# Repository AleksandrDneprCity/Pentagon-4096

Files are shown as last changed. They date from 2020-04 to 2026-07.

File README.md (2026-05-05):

# Pentagon-4096
This is new ZX-Spectrum clone
Версия 10.7.

Актуальные ревизии плат: Материнская плата (MainBoard) - 10.7.1. Верхняя плата (TopBoard) - 5.3.1.

Новый "Pentagon-4096", это новый клон ZX-Spectrum, собранный на классической мелкой логике, но с применением ARV микроконтроллеров.
Новый ZX-Spectrum совместимый компьютер вобрал в себя всё лучшее, что было в оригинальном Pentagon-128, но в него добавлены 
ряд исправлений и дополнений, реализованы ряд функциональных возможностей:

1) Полная совместимость, в том числе и по положению сигнала прерывания INT, с оригинальным "Pentagon-128". Но с возможностью переключения 
положения сигнала INT в положение "Фирменный ZX-Spectrum" (на 16 телевизионных строк вниз + на 13.71 мкс вправо), с целью исключения 
мерцания спрайтов в ряде фирменных играх.

2) Формирование видеосигнала с полностью стандартными синхро-импульсами и импульсами гашения, которые гарантируют нормальную работу с любым 
телевизором, а так же корректную работу PAL/NTSC и при необходимости, SECAM кодера.

3) Наличие PAL/NTSC кодера на микросхеме CXA1645 или CXA2075. Двумя перемычками можно выбирать стандарты: PAL 4.43 MHz, NSTC 3.58 MHz, NTSC 4.43 MHz.

4) Объём оперативной памяти 4 Мб с помощью 1 модуля SIMM 30 pin. Имеется возможность установки 1 модуля SIMM на 1 Мб, на плате имеется 
соответствующий джампер для переключения объёма установленного модуля памяти.

Вначале я хотел сделать ещё вариант установки двух модулей SIMM 30 pin по 1 Мб, но был вынужден отказаться от идеи, т.к. она не подружилась 
с турбированием ОЗУ на 7 МГц. Переключение модулей я делал стандартным способом - коммутацией сигнала CAS, но минимальной задержки 
этого сигнала оказалось достаточно, чтобы компьютер не заработал вообще. Хотя ещё оставалось конечно пару вариантов - коммутацию CAS 
я тогда сделал на К1531КП11, а нужно было попробовать на 1531ЛА3, но уже не буду возвращаться к этому варианту.

Расширении объёма памяти >128 КБ будет многостандартным, набор вариантов расширения памяти зависит от объёма установленного модуля SIMM 30 pin - 1МБ или 4МБ.

4.0: Доступные варианты расширения памяти для модуля SIMM 30 pin 1МБ:

4.0.0) Расширенную верхнюю память вообще можно отключить, оставив стандартные 128 КБ.

4.0.1) По стандарту "Пентагон-1024": За счёт дополнительных двух D6 и D7 битов порта 0x7FFD, а так же за счёт бита D5 (вместо блокировки),
получаем доступный объём ОЗУ 1024 КБ. Для совместимости с некоторыми программами, осбенно с фирменными, бит блокировки D5 этого порта
можно будет переназначать на своё первоначальное назначение - на блокировку всей верхней памяти (48 КБ). В этом случае доступный объём
ОЗУ будет составлять 512 КБ.

0x7FFD бит 7 - 256 КБ

0x7FFD бит 6 - 512 КБ

0x7FFD бит 5 - 1024 КБ (этот бит можно перенастроить на блокировку портов памяти, в этом случае доступный объём ОЗУ составит 512 КБ)

4.0.2) По стандарту "Профи-1024": За счёт порта 0xDFFD, битов D0, D1 и D2, ОЗУ будет доступно в объёме 1024 КБ:

0xDFFD бит 0 - 256 КБ

0xDFFD бит 1 - 512 КБ

0xDFFD бит 2 - 1024 КБ

4.0.3) За счёт чистого порта #1FFD, битов D4 и D7, ОЗУ будет доступно в объёме 512 КБ:

0x1FFD бит 4 - 256 КБ

0x1FFD бит 7 - 512 КБ

4.0.4) По стандарту "Kay-1024": За счёт порта 0x1FFD, битов D4 и D7, и порта #7FFD бита D7, ОЗУ будет доступно в объёме 1024 КБ:

0x1FFD бит 4 - 256 КБ

0x1FFD бит 7 - 512 КБ

0x7FFD бит 7 - 1024 КБ

4.1: Доступные варианты расширения памяти для модуля SIMM 30 pin 4МБ:

4.1.0) Расширенную верхнюю память вообще можно отключить, оставив стандартные 128 КБ.

4.1.1) По стандарту "Пентагон-1024": За счёт дополнительных двух D6 и D7 битов порта 0x7FFD, а так же за счёт бита D5 (вместо блокировки),
получаем доступный объём ОЗУ 1024 КБ. Для совместимости с некоторыми программами, осбенно с фирменными, бит блокировки D5 этого порта
можно будет переназначать на своё первоначальное назначение - на блокировку всей верхней памяти (48 КБ). В этом случае доступный объём
ОЗУ будет составлять 512 КБ.

0x7FFD бит 7 - 256 КБ

0x7FFD бит 6 - 512 КБ

0x7FFD бит 5 - 1024 КБ (этот бит можно перенастроить на блокировку портов памяти, в этом случае доступный объём ОЗУ составит 512 КБ)

4.1.2) По стандарту "Профи-1024": За счёт порта 0xDFFD, битов D0, D1 и D2, ОЗУ будет доступно в объёме 1024 КБ:

0xDFFD бит 0 - 256 КБ

0xDFFD бит 1 - 512 КБ

0xDFFD бит 2 - 1024 КБ

4.1.3) За счёт чистого порта #1FFD, битов D4 и D7, ОЗУ будет доступно в объёме 512 КБ:

0x1FFD бит 4 - 256 КБ

0x1FFD бит 7 - 512 КБ

4.1.4) По смешанному стандарту "Kay-1024" + "Pentagon-1024: За счёт порта 0x1FFD, битов D4 и D7, и порта #7FFD битов D6, D7 и D5, ОЗУ будет доступно в объёме 4096 КБ:

0x1FFD бит 4 - 256 КБ

0x1FFD бит 7 - 512 КБ

0x7FFD бит 6 - 1024 КБ

0x7FFD бит 7 - 2048 КБ

0x7FFD бит 5 - 4096 КБ (этот бит можно перенастроить на блокировку портов памяти, в этом случае доступный объём ОЗУ составит 2048 КБ)

4.1.5) По смешанному стандарту "Profi-1024" + "Pentagon-512: За счёт порта 0xDFFD, битов D0, D1 и D2, и порта #7FFD битов D6, D7, ОЗУ будет доступно в объёме 4096 КБ:

0xDFFD бит 0 - 256 КБ

0xDFFD бит 1 - 512 КБ

0xDFFD бит 2 - 1024 КБ

0x7FFD бит 6 - 2048 КБ

0x7FFD бит 7 - 4096 КБ

4.1.6) По смешанному стандарту "Profi-1024" + порт #1FFD: За счёт порта 0xDFFD, битов D0, D1 и D2, и порта #1FFD битов D4, D7, ОЗУ будет доступно в объёме 4096 КБ:

0xDFFD бит 0 - 256 КБ

0xDFFD бит 1 - 512 КБ

0xDFFD бит 2 - 1024 КБ

0x1FFD бит 4 - 2048 КБ

0x1FFD бит 7 - 4096 КБ

5) Наличие режима "Plus-3". Используются дополнительные 4 страницы ПЗУ, конфигурация ОЗУ становится такой же, как в фирменном 
"ZX-Spectrum+3" с поддержкой режимов "+3 SOS" и "+3 DOS" режимов.

6) В схеме имеется узел, который отлавливает команды короткой адресации к портам IN A,(xx), OUT (xx),A, благодаря которому, как только 
процессор попытается из ОЗУ извлечь код такой команды, моментально будет заблокирована вся верхняя память > 128 КБ, а порт 0x7FFD,
с помощью которого доступно ОЗУ объёмом 128 КБ, будет переведён на мягкую дешифрацию (с помощью битов A1 и A15). Как только процессор попытается из ОЗУ извлечь 
код любой другой команды, верхняя память разблокируется и порт #7FFD снова переводится на жёсткую дешифрацию.

7) Режим "Мультизадачность":
Мультизадачность можно будет включить через BIOS. В случае установленного модуля памяти SIMM 30 pin 4МБ, можно будет загружать в память до 31 задач одновременно.
Если будет установлен модуль памяти SIMM 30 pin 1МБ, то можно будет загружать в память до 7 задач одновременно.
Каждой задаче будет доступно 128 КБ памяти. Последний 32-й блок (или 8-й блок в случае установленного модуля SIMM 30 pin 1МБ) объёмом 128 КБ будет использоваться для хранения данных, необходимых для переключения на задачу.
Переключение между задачами планирую сделать по кнопке "Magic", где будет меню со списком загруженных задач.
 
8) Оперативная память турбирована на 7 МГц. Это позволило:
а) турбировать процессор Z80 на 7 МГц без WAIT-а, получив 200% производительности;
б) турбировать процессор Z80 на 14 МГц с WAIT-ом, получив 290% производительности;
в) реализовать дополнительные видеорежимы, требующие в 2 раза больше циклов доступа к ОЗУ видеоконтроллером, не останавливая процессор:
16 colors и 512х192 пикселей в цвете;

Из недостатков:

Компьютер будет работать не со всеми типами процессоров Z80. Отлично работает Z84C0020PEC, и их не сложно достать, поэтому в данном
проекте нужно использовать только этот процессор.

Возможно, придётся подбирать модули памяти SIMM. Обычно проблем не возникает с 3-чиповыми. В частности, отлично работают Motorolla, 
Samsung и др. Из всех не захотели работать только Panasonic. А вот 9-чиповые глючат, одни больше, другие меньше. из 7 или 8 разных 
модулей мне удалось подобрать только 2, которые более-менее нормально заработали, но всё равно хуже чем 3-чиповые.

Сложность в поиске быстрых микросхем логики серии КР1531. К счастью, не весь компьютер нужно собирать на этой серии, а только критичные 
к задержкам сигналов узлы. А то что достать не удалось, можно заменить на импортые аналоги серии 74Fxxx. 

Из дополнительных недостатков Турбо-14 МГц:

В этом режиме почему-то не хочет работать ОС iS-DOS, который зависает почти сразу после запуска, иногда портится при этом диск C: на HDD.
В то же время, все остальные проверенные мной программы, прекрасно раотают в режиме Турбо-14 МГц.

8) Шина Nemo-Bus v1.0 содержит 4 слота.

9) Возможность установки карт расширения "Plus-3". Для этого есть специальная плата-адаптер "NemobusToDivIDE", в которую можно будет устанавливать карты расширения 3+.
Эта плата устанавливается в слот NemoBus, а на неё саму устанавливается карта +3.

Дополнительная задача платы-адаптера является разрешение конфликтов устройства DivIDE с GeneralSound, у которых совпадают 2 порта 0xB3 и 0xBB.
Для разрешения конфликтов на плате реализован порт 0x33, который управляет блокировкой IORQ на карту +3 и генерацией IORQGE при обращении к портам 0xB3 и 0xBB.
Карта адаптера с установленным в неё DivIDE, должна быть установлена в слот NemoBus с большим приоритетом относительно General Sound. 
Перемычка на карте-адаптере должна быть снята.

В исходном состоянии IORQ на карту +3 не проходит, и IORQGE не генерируется, поэтому при обращении к портам 0xB3 и 0xBB отзываться будет General Sound.
Для того чтобы обратиться к DivIDE, необходимо в порт 0x33 выдать значение 0x10 (бит D4). IORQ для DivIDE разблокируется и при обращении к портам 0xB3 и 0xBB будет генерироваться IORQGE,
таким образом General Sound не будет мешать работе DivIDE.
Для того чтобы вернуть доступ к General Sound, достаточно в порт 0x33 записать значение 0.

Если в карту NemoBusToDivIDE будет установлена любая другая карта +3, которая не конфликтует с General Sound, то можно отключить блокировку IORQ, установив на карте-адаптера перемычку.
В этом случае управлять портом 0x33 не нужно.

11) Плюс 1 слот ISA специально для модема, включенного по схеме Кондратьева, полный вариант с прерыванием от модема IRQ4 по NMI. Использовать 
можно, к примеру, в iS-DOSе, можно будет с ПЦ и обратно перекачивать файлы размером больше дискеты, не придётся дёргать винчестер 
и подключать его к ПЦ. Испытал на себе, это удобно. Сигнал IORQG для модема будет последним в приоритете после 4-го слота ZX-Bus.

12) Наличие мышки PS/2, контроллер на Attiny2313, с буфером, без WAITа.

13) Возможность подключения как классической механической клавиатуры, так и PS/2 без WAIT, контроллер на ATMega48PA-PU.

14) Наличие порта RS-232 с использованием музыкального сопроцессора AY и микросхемы MAX3232.

15) Турбирование контроллера дисковода КР1818ВГ93 по правильной схеме, с учётом всех исправлений описанных журнале "Спектрофон" № 12 и 14.

16) NemoIDE контроллер.

17) Доступ к 0-й странице ПЗУ с прошивкой Gluk Reset Service.

18) Наличие порта атрибутов, с использованием полной дешифрации порта 0xFF.

19) Теневое ОЗУ ёмкостью 128 Кб. Будет выполнять 2 функции - в качестве стандартного теневого ОЗУ, включающееся и выключающееся через 
чтение из портов 0xFB, 0x7B, ёмкостью 16 или 32 Кб, и для подмены всех 8х страниц ПЗУ Spectrum:

Страница 0 - стандартное теневое ОЗУ через IN A,(#FB)/IN A,(#7B), либо эмуляция 0-й страницы ПЗУ Gluk Reset Service;

Страница 1 - только эмуляция 1-й страницы ПЗУ TR-DOS;

Страница 2 - расширение стандартного теневого ОЗУ до 32Кб, либо эмуляция 2-й страницы ПЗУ Menu-128;

Страница 3 - только эмуляция 3-й страницы ПЗУ Basic-48.

Страница 4 - эмуляция 0-й страницы ПЗУ Редакто Basic-128 +3

Страница 5 - эмуляция 1-й страницы ПЗУ Обработчик ошибок Basic-128 +3

Страница 6 - эмуляция 2-й страницы ПЗУ Basic-48 +3

Страница 7 - эмуляция 3-й страницы ПЗУ +3 DOS

19) Микросхема CMOS-часиков по схеме MrGluk. Можно устанавливать как Dallas, так и МС146818 или её аналог 512ВИ1. Тактирование последних 
двух происходит от экономичной микросхемы MC14069. Внешняя батарейка - CR2032, которая будет использоваться для любого варианта CMOS, 
в том числе и для Dallas (в случае, если используется старый чип Dallas с давно разряженной внутренней батарейкой).
Порты для управления CMOS - 0xBFF7, 0xDFF7 и 0xEFF7.

20) 9 расширенных видеорежимов (в скобках кол-во циклов доступа к ОЗУ видеоконтроллером за 1 адрес):

20.0) "Стандартный видеорежим". 256х192 pix, атрибут цвета на знакоместо 8х8, разрешение для атрибутов 32х24. Область пикселей - 0x4000 - 0x57FF, область атрибутов - 0x5800 - 0x5AFF 
(2 цикла чтения из ОЗУ);

20.1) "Аппаратный мультиколор". 256х192 pix, атрибут цвета на байт 8х1, разрешение для атрибутов 32х192. Область пикселей - 0x4000 - 0x57FF, область атрибутов - 0x6000 - 0x77FF 
(2 цикла чтения из ОЗУ);

20.2) "512х192 pix, монохромный". Через порт BIOS можно выбрать любой цвет текста. Область пикселей нечётного знакоместа - 0x4000 - 0x57FF, область 
пикселей чётного знакоместа - 0x6000 - 0x77FF (4 цикла чтения из ОЗУ, для совместимости с цветным вариантом);

20.3) "512х192 pix, цветной". Атрибут на знакоместо 8х8, разрешение для атрибутов 64х24. Область пикселей нечётного знакоместа - 0x4000 - 0x57FF, область 
атрибутов нечётного знакоместа - 0x5800 - 0x5AFF, область пикселей чётного знакоместа - 0x6000 - 0x77FF, область атрибутов чётного 
знакоместа - 0x7800 - 0x7AFF (4 цикла чтения из ОЗУ);

20.4) "512х192 pix, мультиколорный". Атрибут на байт 8х1, разрешение для атрибутов 64х192. Область пикселей нечётного знакоместа - 0x4000 - 0x57FF, область пикселей 
чётного знакоместа - 0x6000 - 0x77FF, область атрибутов нечётного знакоместа - 0xC000 - 0xD7FF 4-й страницы, область атрибутов чётного 
знакоместа - 0xE000 - 0xF7FF 4-й страницы (4 цикла чтения из ОЗУ);

20.5) "16 colors" - каждый пиксель своим цветом. Экран состоит из 4-х экранных областей: 0x4000 - 0x57FF, 0x6000 - 0x77FF, 0xC000 - 0xD7FF 
4-й страницы, 0xE000 - 0xF7FF 4-й страницы. Каждый байт данных отображает 2 пикселя, каждая экранная область отображает свои 2 пикселя из знакоместа, 4 области составляют целое знакоместо (4 цикла чтения из ОЗУ);

20.6) "384х288 pix, полноэкранный режим без бордюра". Разрешение для атрибутов 48х36 (2 цикла чтения из ОЗУ);

20.7) "FlashColor". Можно применять в комбинации с видеорежимами 20.0, 20.1, 20.3, 20.4 и 20.6. Внутри каждого цветного атрибута, в котором активирован 7-й бит "флеш", вместо стандартного мигания знакоместа, перемешиваются цвета пикселей и фона и выводятся результат для пикселей, цвет фона при этом чёрный.

20.8) "Аппаратный GigaScreen", автоматический. Можно применять в комбинации с любым видеорежимом. Выводит на экран основной и дополнительный экраны с черезстрочным чередованием, с инверсией переключения через кадр. Включается при условии, если программа просмотра гигаскрин-картинок начинает переключать по прерываниям основной / дополнительный экран. Когда переключение произошло, запускается переключение экранов через строку и продолжается до прихода кадрового импульса. Если программное переключение экранов прекратилось, аппаратный гигаскрин не включается. За счёт черезстрочного переключения экранов, мерцание на гигаскрин картинках становится значительно менее заметно.

Видеорежимы "Аппаратный мультиколор", "512х192", "16 colors" и "384х288" включаются стандартным портом 0xEFF7.
Видеорежим "512х192" из монохромного в цветной или обратно переключается дополнительным портом 0xFE37, управляемый из BIOS.
Видеорежим "512х192" мультиколорный включается, если через 0xEFF7 включить одновременно режимы "Мультиколор" и "512х192", а так же 
включить цвет портом 0xFE37.

20.9) Регистр палитры (совместим с АТМ Турбо 2+): Возможность переопределять стандартные 16 цветов на любые из палитры 4096 цветов. Палитра обеспечивает 12 битный цвет: для каждой компоненты R, G, B можно задавать любое 4-битное значение. Таким образом получается по 16 уровней для красного, зелёного и синего, что в совокупности даёт 4096 цветов и оттенков.

Программируется палитра в момент, пока на экране отображается бордюр. Для этого необходимо сначала задать номер исходного цвета из 16, который необходимо переназначить, включив соответствующий Border:

биты 0, 1 и 2 - записывая в порт #FE значения от 0 до 7, бит 3 - записывая в порт #F6 значение 8.

Затем задать нужный цвет из палитры путём записи в порт # xxFF значение цвета. При этом по шине данных задаются первые 6 бит цвета, а по шине адреса - вторые 6 бит.

Раскладка 12-битного цвета при записи в порт #xxFF:

||| Палитра: ||| R0... | R1... | R2... | R3... ||| G0... | G1... | G2... | G3... ||| B0... | B1... | B2... | B3... |||

||| Порт #FF ||| A14 | A9... | D6... | D1... ||| A15 | A12 | D7... | D4... ||| A13 | A8... | D5... | D0... |||

21) SoundDrive с поддержкой режима Covox. В качестве микросхем ЦАП использованы TLC7528, что значительно упростило принципиальную схему.

22) BIOS с тестированием ОЗУ и Setup-ом. Установлена дополнительная микросхема ПЗУ ёмкостью 64 Кбайта. 

22.1) В BIOS-Setup можно:

22.1.1. Выставлять текущую дату и время;

22.1.2. Настроить расширенные видеорежимы:

а) выбрать цвет текста для монохромного видеорежима 512х192;

б) включить или отключить цвет для видеорежима 512х192;

в) включить или отключить флешколор;

г) включить или отключить автоматический аппаратный гигаскрин.

3. Настроить теневое ОЗУ - включать и отключать эмуляцию ПЗУ для каждой из 4-х страниц;

4. Настроить поведение Спектрума при сбросе:

а) Выход в Gluk Reset Service;

б) Выход в Menu-128;

в) Выход в TR-DOS;

г) Выход в TR-DOS без очистки ОЗУ;

д) Выход в Basic-48;

е) Загрузка с HDD Master;

ж) Загрузка с HDD Slave;

з) При выборе варианта загрузки с HDD, можно выбирать варианты, что именно загружать:

DNA-OS;

iS-DOS;

пользовательский вариант номера блока LBA.

22.1.3. Выбрать порты расширения верхней памяти >128 КБ;

22.1.4. Включать и отключать режим Мультизадачности.

23) Конструктивно всё это собрано на двух платах: Материнская плата имеет размер стандартного ATX, что позволит её установить 
в стандартный корпус ATX, разводка 4-слойная. Вторая плата имеет размеры 170x170 мм и будет крепиться к материнской плате вверху 
и на ней будут располагаться 5 внешних коннекторов: Сдвоенный PS/2 - мышка + клавиатура, DB15 (female) - механическая клавиатура, 
DB9 (female) - кэмпстон джойстик, DA-15 (VGA), S-Video и RCA 3 шт - видео и аудио стерео. 
Остальные коннекторы - 3 шт. мини-джек (аудио-выход, магнитофонные вход и выход), DB9 (male - порт RS-232) и DB25 (принтер) придётся 
разместить на планках.

Описание портов BIOS:

#FC37 "Конфигурация памяти":

    bit 0, 1 - выбор 1-го порта расширения ОЗУ > 128 КБ (EM0):
    0 - выкл,
    1 - Пентагон-1024 (#7FFD)
    2 - Профи-1024 (#DFFD)
    3 - Scorpion/KAY (#1FFD)

    bit 2, 3 - выбор 2-го порта расширения ОЗУ > 128 КБ (EM1):
    0 - выкл,
    1 - Пентагон-1024 (#7FFD)
    2 - Профи-1024 (#DFFD)
    3 - Scorpion/KAY (#1FFD)

Совместное использование 1-го и 2-го портов расширения (EM0 и EM1) подчиняется следующей таблице:

        Биты порта #FC37:
        3  2     1  0
        EM1      EM0          SIMM 1M          SIMM 4M            Max Size                                      Size (без участия бита защёлки D5 7FFD)
    
    0)  0  0     0  0         128K             128K                128K                                          128K
    1)  0  0     0  1         Pent-1M          Pent-1M              1M (#7FFD биты 6, 7, 5)                      512K (#7FFD биты 6, 7)
    2)  0  0     1  0         Profi-1M         Profi-1M             1M (#DFFD биты 0, 1, 2)                       1M (#DFFD биты 0, 1, 2)
    3)  0  0     1  1         #1FFD            #1FFD               512K (#1FFD биты 4, 7)                        512K (#1FFD биты 4, 7)
    4)  0  1     1  1         KAY-1M           KAY-1M+Pent          4M (#1FFD биты 4, 7, #7FFD биты 6, 7, 5)      2M (#1FFD биты 4, 7, #7FFD биты 6, 7)
    5)  1  0     1  0         Profi-1M         Profi-1M+Pent        4M (#DFFD биты 0, 1, 2, #7FFD биты 6, 7)      4M (#DFFD биты 0, 1, 2, #7FFD биты 6, 7)
    6)  1  1     1  0         Profi-1M         Profi-1M+1FFD        4M (#DFFD биты 0, 1, 2, #1FFD биты 4, 7)      4M (#DFFD биты 0, 1, 2, #1FFD биты 4, 7)

Примечание-1: В любой из выбранной конфигурации ОЗУ, где задействуется бит 5 порта #7FFD для расширения ОЗУ, доступность такого расширения зависит от опции BIOS "Бит 5 #7FFD защёлка или расширение".

Примечание-2: Конфигурация № 5 является исключением из правил - для задействования двух портов #DFFD и #7FFD, EM0 и EM1 оба должны быть = 2.

    bit 4 - опция "Бит 5 #7FFD защёлка или расширение". Если этот бит = 0, тогда бит 5 порта #7FFD расширяет ОЗУ, в противном случае работает как обычная защёлка 48 КБ.
    bit 5 - включение режима загрузки данных в статическое ОЗУ. При активации этого бита, в адреса #C000 - #FFFF вместо основного ОЗУ подставляется статическое ОЗУ с полным доступом. 
Выбор страницы статического ОЗУ осуществляется через порт #7FFD битами 0 и 1, что даёт доступ в пределах 64 КБ, а так же включение или отключением режима "3+", что даёт выбор между первыми и вторыми 64 КБ статического ОЗУ. Если в порту #7FFD активировать бит 2, то вместо статического ОЗУ снова включается основное ОЗУ. Сделал это для возможности использовать отладчик STS 3.3, который висит в 7-й странице ОЗУ.
    bit 6 - включение режима "Мультизадачность".
    bit 7 - включение режима "3+".

#FD37: - выбор страниц эмуляции основного ПЗУ в статическом ОЗУ. При активации какого-либо бита этого порта, выбранная страница основного ПЗУ, которая соответствует биту порта BIOS, подменяется на соответствующую страницу из статического ОЗУ. В этом режиме выбранные страницы статического ОЗУ доступны в режим "только чтение".

#FE37: - дополнительные видеорежимы.

    bit 0, 1, 2 - цвет текста (B, R, G) в монохромном режиме 512x192.
    bit 3 - яркость текста в монохромном режиме 512x192.
    bit 4 - включение цвета в режиме 512x192.
    bit 5 - видеорежим "FlashColor".
    bit 6 - видеорежим "Аппаратный GigaScreen с автовключением".
    bit 7 - выбор положения INT: 0 = Пентагон, 1 = Фирменный.

#FF37: - управление ПЗУ и блокировками.

    bit 0 - отключает ПЗУ BIOS и включает основное ПЗУ "Spectrum".
    bit 1 - отключает блокировку защёлки сервисной страницы ПЗУ "Gluk Reset Service".
    bit 2, 3 - выбор страницы ПЗУ BIOS в пределах первых 3-х страниц. Последняя страница ПЗУ BIOS задействована в качестве ПЗУ Принтера, поэтому недоступна для режима BIOS.
    bit 4 - блокировка включения режима "кеш память".
    bit 5 - разрешает запись в регистры палитры.
    bit 6 - включение режима записи в основное ПЗУ "Spectrum".
    bit 7 - включение режима стирания основного ПЗУ "Spectrum".

Раскладка порта конфигурации #EFF7:

    bit 0 - видеорежим "16 Colors" - каждый пиксель своим цветом.
    bit 1 - видеорежим "512х192" - удвоенное разрешение по горизонтали.
    bit 2 - не используется.
    bit 3 - проецирование 0-й страницы ОЗУ в адресное пространство ПЗУ #0000 - #3FFF.
    bit 4 - не используется.
    bit 5 - видеорежим "Мультиколор" - атрибут цвета на байт.
    bit 6 - видеорежим "384x304" - экран без бордюра.
    bit 7 - открытие скрытых портов RTC и FDC.
    
Видеорежимами можно управлять двумя портами: 

#EFF7 - основной стандартный порт управления видеорежимами;

#FE37 - дополнительный порт BIOS управления видеорежимами.

        #EFF7:                  #FE37:
    0)  X 0 0 0 - X 0 0 0       X 0 0 X - X X X X        Стандартный видеорежим
    1)  X 0 1 0 - X 0 0 0       X X X X - X X X X        "Аппаратный мультиколор" (атрибут цвета на байт)
    2)  X 0 0 0 - X 0 0 1       X X 0 X - X X X X        "16 Colors" (каждый пиксель своим цветом)
    3)  X 0 0 0 - X 0 1 0       X X X 0 - I G R B        "512x192 монохромный", цвет текста задаётся битами I G R B порта #FE37
    4)  X 0 0 0 - X 0 1 0       X X X 1 - X X X X        "512x192 цветной", атрибут цвета на узкое знакоместо размером 8х8 пикселей
    5)  X 0 1 0 - X 0 1 0       X X X 1 - X X X X        "512x192 цветной мультиколорный" - атрибут цвета на узкий байт размером 8x1 пикселей
    6)  X 1 0 0 - X 0 0 0       X X X X - X X X X        "384x304" - экран без бордюра, количество пикселей без учёта строчных и кадровых гасящих импульсов
    7)  X X X 0 - X 0 X 0       X X 1 X - X X X X        "FlashColor" - бит 7 атрибута цвета вместо мигания активирует палитру INK (кроме монохромного режима 512х192 и 16 Colors)
    8)  X X X 0 - X 0 X X       X 1 X X - X X X X        "Аппаратный GigaScreen" - перекл. осн. и доп. экран каждую строку, вкл/выкл автоматически по факту программного переключения экранов

Примечание-1:
При включении через порт #FE37 режима "Аппаратный GigaScreen", фактически он включается с момента однократного программного переключения экранов, осуществляя их аппаратное переключение вначале каждой строки, и отключается в конце кадра.

Примечание-2:
Видеорежим "16 Colors" не совместим с видеорежимами "Мультиколор", "512x192" цветным и монохромным, "384x304" и "FlashColor".

Примечание-3:
Видеорежим "384x304" не совместим с видеорежимами "Мультиколор", "512x192" цветным и монохромным и "16 Colors".

Примечание-4:
Видеорежим "Аппаратный GigaScreen" совместим со всеми остальными видеорежимами, его можно комбинировать с любым другим видеорежимом.

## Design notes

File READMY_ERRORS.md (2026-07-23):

Обнаруженные ошибки в схеме:

Материнская плата, версия 10.7:

1) При открытии портов TR-DOS (при открытии доступа к чипу RTC - Real Time Clock) через порт #EFF7 бит 7, возникает конфликт портов TR-DOS с портами конфигурации #EFF7 и портом атрибутов #FF.
  Необходимо в дешифратор портов TR-DOS добавить проверку адреса A3 на 1.
  В более простом варианте решения, необходимо перекинуть местами 2 логических элемента: 4И (DD15.2 - 1533ЛИ6) и 2И (DD132.2 - 1533ЛИ1). На два свободных входа ЛИ6 подаём дополнительные адреса от процессора A2 и A3.
2) На адресный вход A1 микросхемы контроллера дисковода КР1818ВГ3 (DD135 выв.6) перепутал адрес от процессора - подал A1 вместо A6.
   Отрезаем A1 от выв.6 DD135 (1818ВГ93) и подаём туда A6.
3) Не соединил вместе выводы 28 (HLD) и 32 (RDY) микросхемы контроллера дисковода КР1818ВГ93.
   Соединяем между собой выводы 28 и 32 DD135 (1818ВГ93).
4) С учётом особенностей применения в качестве регистра пикселей, микросхемы КР1533ИР9 вместо двух привычных микросхем К555ИР16, требуется дополнительная небольшая задержка тактового сигнала,
   при чём для двух видеорежимов 256x192 и 512x192 пикселей задержка должна быть разной, для 256x192 больше, а для 512x192 меньше.
   а) ёмкость конденсатора C6 возле ИР9 уменьшаем со 100 до 47 пф (начинает работать видеорежим 512х192).
   б) отрезаем от входа микросхемы DD104 (1531КП11) выв.11 сигнал F7 и подаём его туда через резистор 680 Ом, вешаем конденсатор 47 пф между землёй и выв.11 этй же микросхемы.
5) Ошибка в ловушке команд OUT (xx),A и IN A,(xx), предназначенной для разрешения конфликтов портов расширения ОЗУ выше 128 КБ (1FFD, DFFD) при использовании команд короткой адресации порту FD.
   а) отрезаем сигнал ММ1 от выв.11 DD68.1 (1533ТМ2);
   б) подаём на выв.11 DD68.1 (1533ТМ2) инверсный сигнал M1 прямо с процессора с выв.27.
   в) желательно закоротить резистор R7 в цепи инверсного сигнала M1, в таком случае на микросхему DD68 его можно подать от соседней микросхемы на плате.
6) Порт #1FFD +3: При обращении к этому порту, ошибочно использовал сигнал WR, который подан на микросхему DD78.4 (1533ЛЕ1) выв.12. Вместо сигнала WR туда необходимо подать сигнал WRHR,
   в который заведены блокировки: при срабатывании ловушки команд OUT (xx),A и IN A,(xx), при блокировке памяти выше 48 КБ через порт #7FFD бит 5.
   а) отрезаем сигнал WR от выв.12 DD78;
   б) подаём сигнал WRHR, соединяя между собой выводы 3 и 12 DD78.   
7) С учётом применения буфера шины данных на 1531АП6, необходимо чуть-чуть притормозить тактовые сигналы портов #FE (бордюр, биппер) и #EFF7.
   Берём 2 конденсатора по 220 пф, припаиваем их: между выв.9 DD147 (ТМ9) и землёй, и между выв.9 DD93 (ТМ9) и землёй.
8) Ошибка в схеме многозадачности:
   При включении многозадачности сигналом BIOS "MTASK_ON", необходимо чтобы биты расширения ОЗУ выше 128 КБ, вместо привычного проецирования выбранной страницы 16 КБ в адресное окно #C000 - #FFFF,
   производили замену целого блока ОЗУ размером 128 КБ на выбранный. Так же необходимо на выбранный блок 128 КБ проецировать оба экрана.
   Для исправлении ошибки понадобятся дополнительный логический элемент И на 1531ЛИ1, и любой инвертирующий элемент.
   а) дополнительный элемент "И" можно взять DD54.3 или DD54.4, если вместо 1533ЛИ1 установлена 1531ЛИ1. Оба логических элемента в схеме по ошибке выполняют одну и ту же функцию с одними и теми же сигналами.
   Освобождаем один из них, переложив всё на другой элемент;
   б) в качестве инвертирующего элемента моожно использовать свободный элемент DD113.4 (ЛП5);
   в) формируем инверсный сигнал "MTASK_ON" с помощью элемента DD113.4 (ЛП5). На вход-1 подаём прямой сигнал "MTASK_ON", на вход-2 подаём +5 вольт;
   г) с помощью полученного логического элемента DD54.3 или DD54.4 (1531ЛИ1) формируем новый инверсный сигнал "HRAM": На вход-1 подаём инверсный сигнал "A14 & A15", на вход-2 подаём инверсный сигнал "MTASK_ON"
   с выв.11 DD113.4 (ЛП5);
   д) отрезаем мнверсный сигнал "A14 & A15" от выв.1 и 15 DD84 и DD86 (1531КП12), от выв.7 DD85 (1531КП7);
   е) полученный новый инверсный сигнал "HRAM" подаём на выв.1 и 15 DD84 и DD86 (1531КП12) и выв.7 DD85 (1531КП7).
9) Питание микросхемы RTC часов (DD94):
   а) диод шоттки VD3 необходимо заменить на обычный диод 1N4148 или отечественный КД521, КД522. Это сильно продлит жизнь 3-вольтовой батарейке.
   У диодов шоттки 1N5817 обратное сопротивление составляет около 20 кОм. При выключенном БП, батарейка разряжается через обратное сопротивление 20 кОм диода VD3 на схему компьютера.
   Ток утечки при этом составляет 3 вольт / 20 кОм = 0.15 мА. При ёмкости новой батарейки 250 мА/час, только из-за утечки VD3, она полностью разрядится за 250 / 0.15 = 1667 часов или за 70 суток.
   Падение напряжения 0.6 вольт при питании от БП для микросхемы RTC не принципиально.
   Диод VD4 должен оставаться шоттки 1N5817, падение напряжения от батарейки должно быть минимальное, тут без вариантов.

Верхняя плата, версия 5.3:

1) Отсутствие резисторов подтяжки к земле для аудио-выходов музыкального сопроцессора.
   Берём 3 резистора номиналом 6.2 кОм и припаиваем их между выодами аудио-каналов A, B, C и землёй.
   б) можно добавить дополнительное питание микросхемы RTC от дежурного режима БП, подав дополнительные +5 вольт от разъёма ATX выв.9, через диод 1N4148, в точку соединения катодов VD3 и VD4.
   Батарейка не будет разряжаться в дежурном режиме, когда БП, хотя и выключен, но подключен шнуром в электросеть.

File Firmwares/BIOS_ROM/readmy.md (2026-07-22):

BIOS ROM v4.2 для нового Pentagon-4096.
Выпуск 22.07.2026.

Переходная версия BIOS после версии 3.2 для Pentagon-1024 1.4, доработанного под Pentagon-4096.

History versions:

v3.2
Базовая версия BIOS для старой версии Pentagon-1024 1.4.

v4.2
- Адаптирован под новый Pentagon-4096, с учётом изменения раскладки портов BIOS, и с учётом увелниения объёма статического ОЗУ с 64 до 128 КБ.
- Тест статического ОЗУ расширен до 128 КБ и до 8 функций эмуляции ПЗУ Spectrum:
    Gluk Reset;
    TR-DOS;
    Menu-128;
    Basic-48;
    3+Menu-128;
    3+Sintax-128;
    3+DOS;
    3+Basic-48.

- Добавлена инициализация палитры стандартными цветами.
- Пока что фиксированное включение расширения основного ОЗУ до 4 МБ по стандарту Pentagon + Profi, с активацией возможности блокировки верхней памяти через порт #7FFD бит-5.
- Дополнил меню BIOS Setup / Статическое ОЗУ (пока что прописано старое название "Shady RAM") пунктами включения эмуляции новых страниц ПЗУ для режима Spectrum +3.

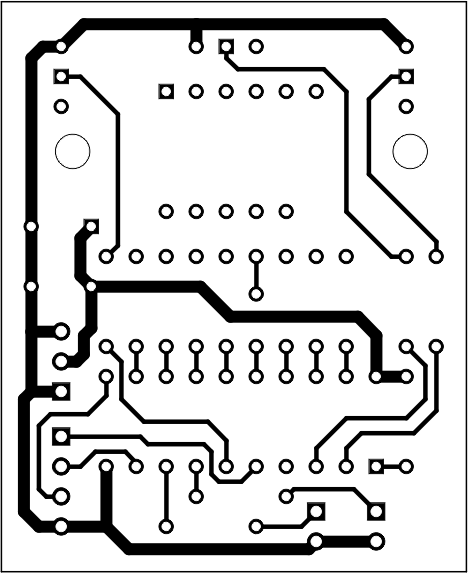
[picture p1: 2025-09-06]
Hardware/Export/PNG/FreqInd-v1-pcb-layer-bottom.png

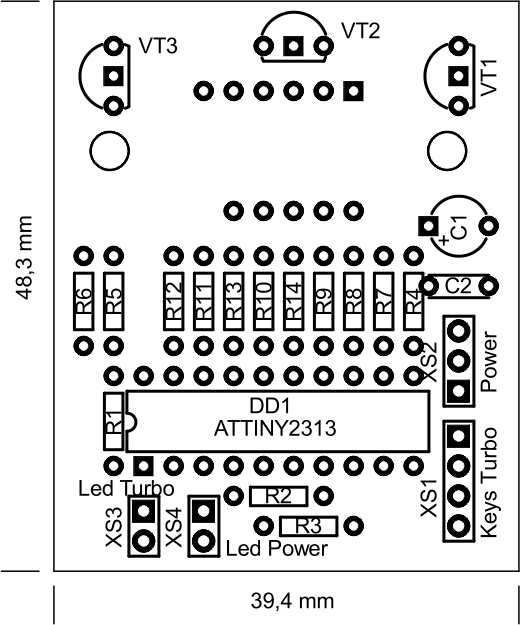
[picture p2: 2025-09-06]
Hardware/Export/PNG/FreqInd-v1-pcb-comp-top.png

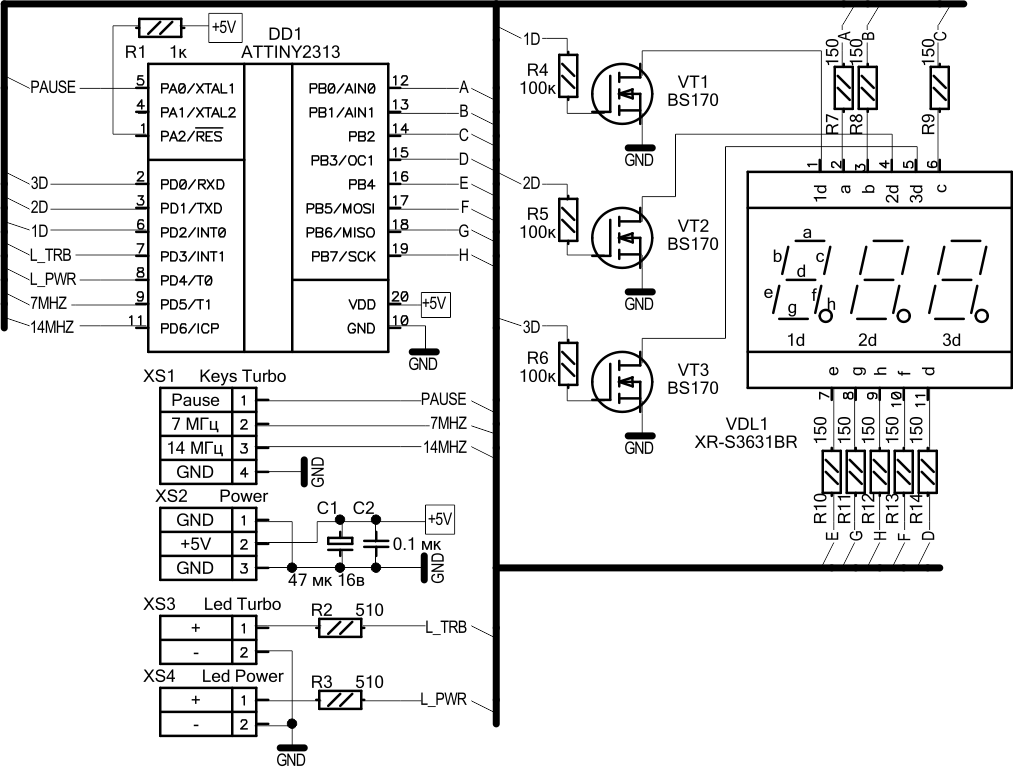
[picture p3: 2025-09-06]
Hardware/Export/PNG/FreqInd-sch.png

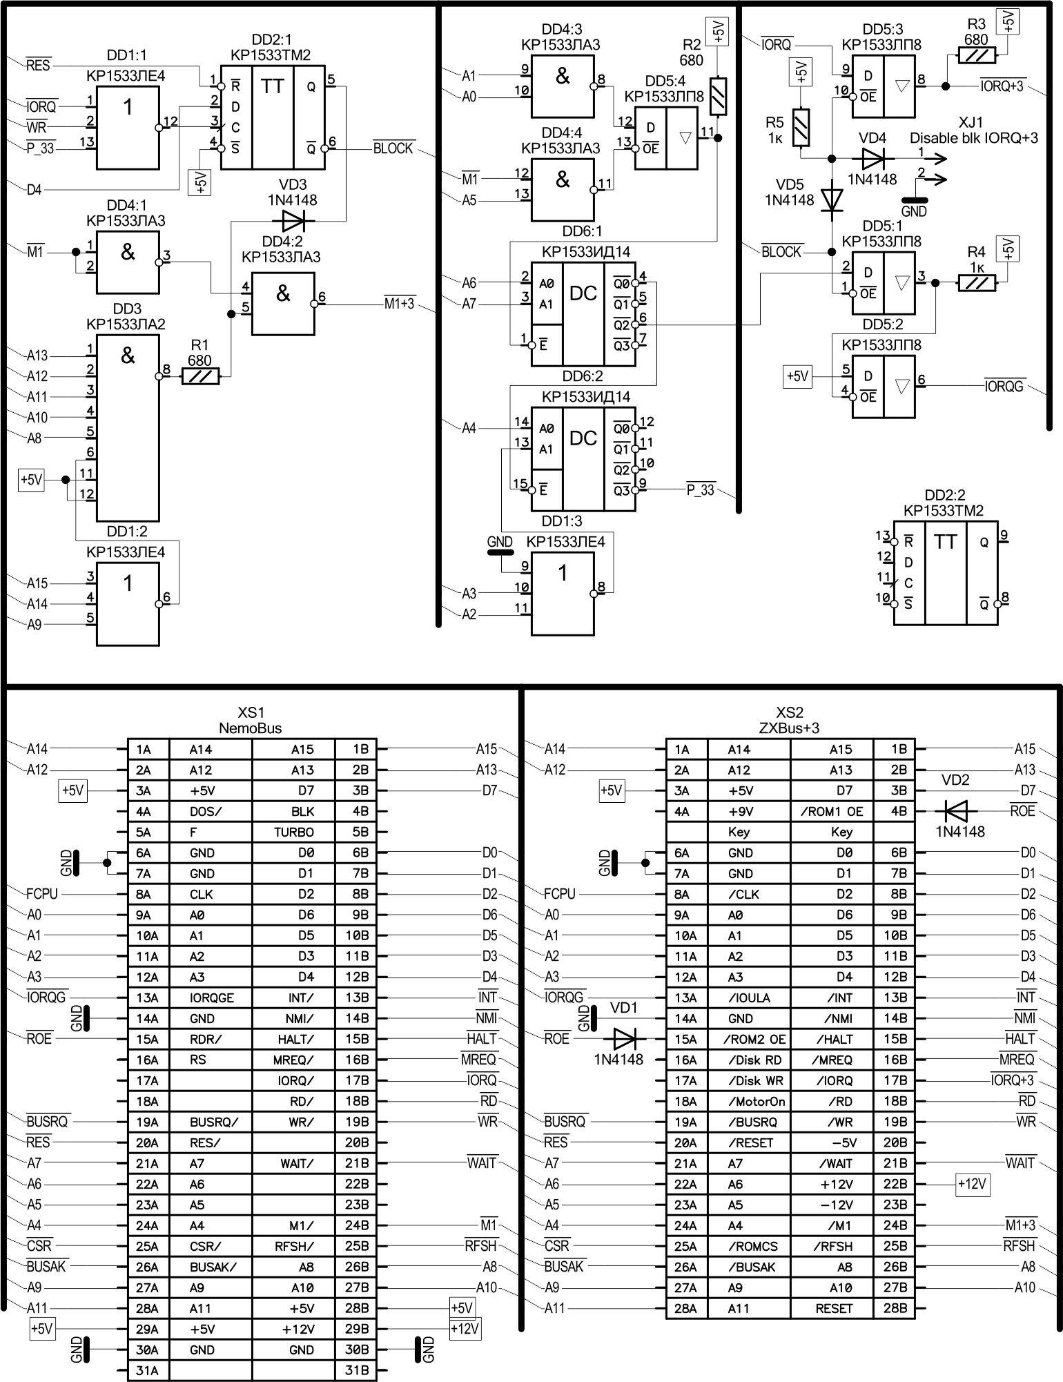
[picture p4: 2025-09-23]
Hardware/Export/PNG/NemoBusToDivIDE-v1.3-sch.png

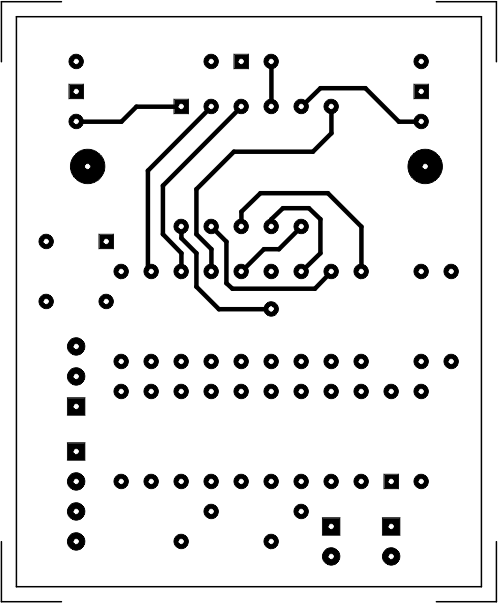
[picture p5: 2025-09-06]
Hardware/Export/PNG/FreqInd-v1-pcb-layer-top-fotores.png

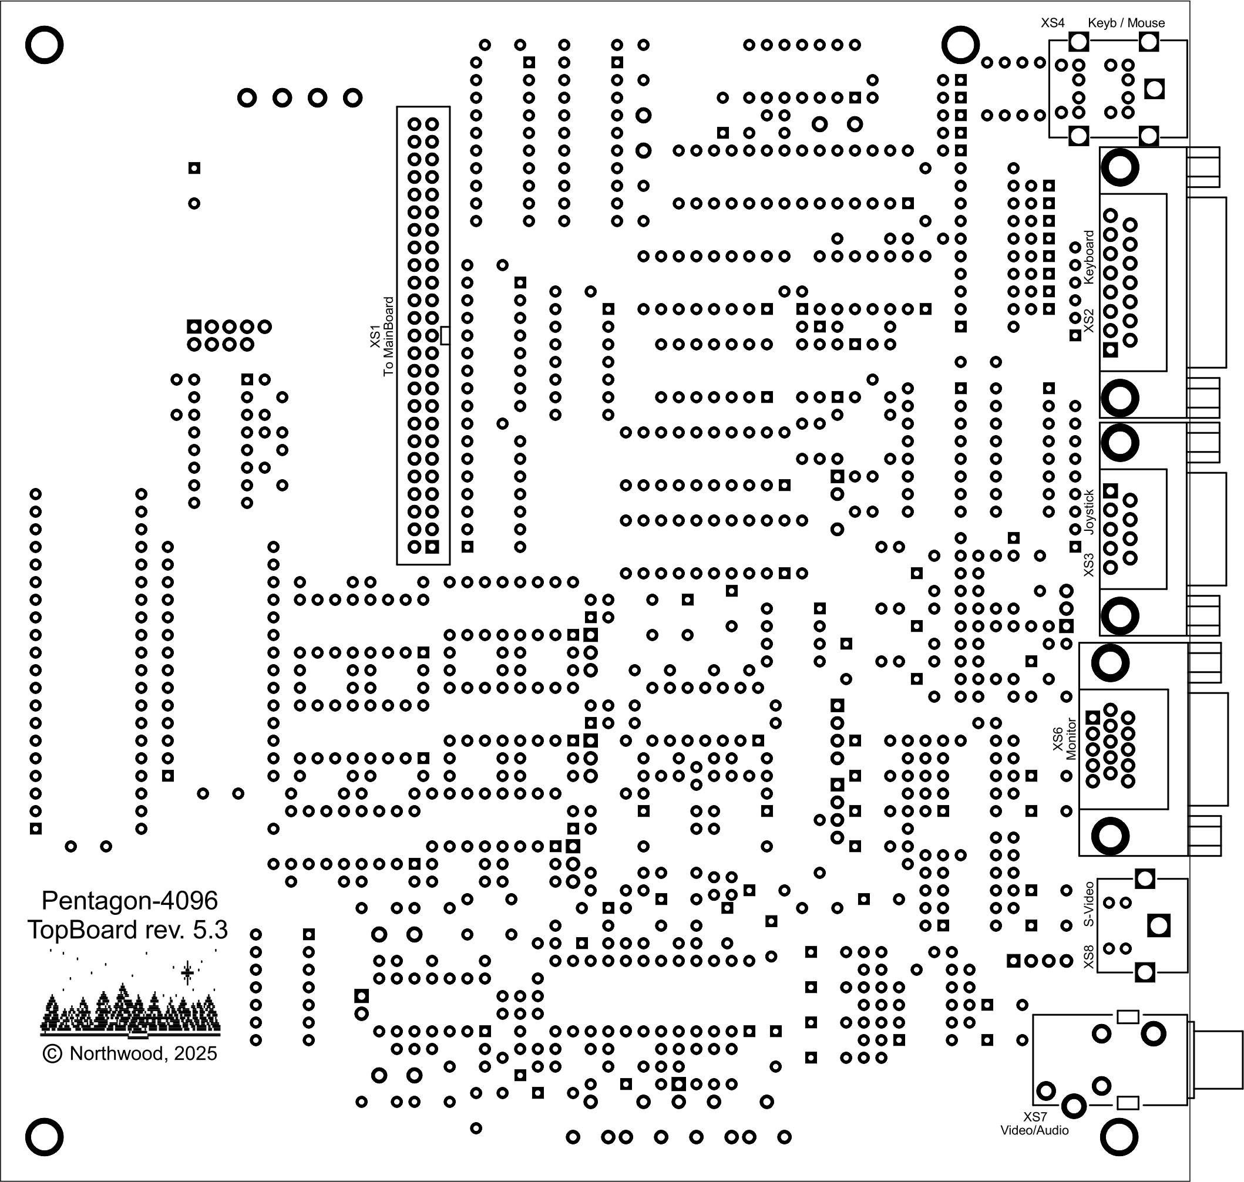
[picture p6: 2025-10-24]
Hardware/Export/PNG/TopBoard-v5.3-pcb-comp-bottom.png

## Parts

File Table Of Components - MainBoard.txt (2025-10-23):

Резисторы:

МЛТ-0.125:

330 Ом		7шт.
430 Ом		1шт.
470 Ом		4шт.
510 Ом		1шт.
560 Ом		1шт.
680 Ом		22шт.
1 кОм		9шт.
2.2 кОм		4шт.
3 кОм		2шт.
6.8 кОм		16шт.
10 кОм		26шт.
22 кОм		3шт.
2 МОм		1шт.

Конденсаторы:

Керамические:

27 пф		1шт.
33 пф		1шт.
100 пф		1шт.
200 пф		1шт.
300 пф		3шт.
1 нф		1шт.
6.8 нф		1шт.
10 нф		1шт.
0.1 мкф		65шт.
0.22 мкф	2шт.

Электролитические:

10 мкф 10в	2шт.
100 мкф 16в	2шт.
220 мкф 10в	1шт.
1000 мкф 10в	2шт.
2200 мкф 10в	1шт.

Кварцевые резонаторы:

32.768 КГц	1шт.
8 МГц		1шт.
14 МГц		1шт.

Диоды:

1N4148		8шт.
1N5817		7шт.

Стабилитрон:
5.1V		1шт.

Транзисторы:

КТ315Б		2шт.

Микросхемы:

Аналоговые:
LM7905 (TO220)	1шт.

Цифровые:

КР1531АП5		1шт.		74F244
КР1531АП6		2шт.		74F245
КР1531ИД7		2шт.		74F138
КР1531ИД14		1шт.		74F139
КР1531ИЕ17		2шт.		74F169
КР1531ИР22		2шт.		74F373
КР1531ИР23		2шт.		74F374
КР1531КП2		2шт.		74F153
КР1531КП7		3шт.		74F151
КР1531КП11		2шт.		74F257			DD82, DD83
КР1531КП11 / КП16	4шт.		74F257 / 74F157		DD45, DD46, DD104, DD105
КР1531КП12		10шт.		74F253
КР1531ЛА1		1шт.		74F20
КР1531ЛА3		3шт.		74F00
КР1531ЛА4		1шт.		74F10
КР1531ЛЕ1		2шт.		74F02
КР1531ЛЕ4		1шт.		74F27
КР1531ЛИ1		5шт.		74F08
КР1531ЛИ3		2шт.		74F11
КР1531ЛЛ1		9шт.		74F32
КР1531ЛН1		3шт.		74F04
КР1531ЛП5		3шт.		74F86
КР1531ТМ2		4шт.		74F74
КР1531ТМ8		1шт.		74F175

КР1533АГ3		1шт.		74ALS123
КР1533ИД7		3шт.		74ALS138
КР1533ИЕ5		1шт.		74ALS93
КР1533ИЕ10		1шт.		74ALS161
КР1533ИЕ19		2шт.		74ALS393
КР1533ИР9		1шт.		74ALS165
КР1533ИР22		3шт.		74ALS373
КР1533ИР23		4шт.		74ALS374
КР1533ИР35		4шт.		74ALS273
КР1533КП2		2шт.		74ALS153
КР1533ЛА2		6шт.		74ALS30
КР1533ЛА3		2шт.		74ALS00
КР1533ЛА4		1шт.		74ALS10
КР1533ЛЕ1		5шт.		74ALS02
КР1533ЛИ1		7шт.		74ALS08
КР1533ЛИ3		1шт.		74ALS11
КР1533ЛИ6		1шт.		74ALS21
КР1533ЛЛ1		9шт.		74ALS32
КР1533ЛН1		5шт.		74ALS04
КР1533ЛП8		1шт.		74ALS125
КР1533ТМ2		9шт.		74ALS74
КР1533ТМ8		3шт.		74ALS175
КР1533ТМ9		4шт.		74ALS174

К555ИР16		1шт.		74LS295
К555ИР23		1шт.		74LS374
К555ЛН2			1шт.		74LS05
К555ТМ2			1шт.		74LS74
К555ТМ9			1шт.		74LS174

MC14069			1шт.

27C512			1шт.
ATtiny13A		1шт.
IS61C1024		1шт.
HM6818A			1шт.
SIMM 30PIN 4MB		1шт.
W27C010			1шт.
Z84C0020PEC		1шт.
КР1818ВГ93		1шт.

Разъёмы:

Jump 2 pin	5шт.		Обычные 2 штырька на плату под перемычку.
Jump 3 pin	10шт.		Обычные 3 штырька на плату под перемычку на 2 положения.

BH-26		1шт.		Разъём на плату, аналогичный как IDE, но на 26 контактов, либо просто 2 ряда штырьков по 13 контактов. Для подключения планки LPT.
BH-34		1шт.		Разъём на плату для подключения дисковода FDD.
BH-40		1шт.		Разъём на плату для подключения HDD.
BH-50		1шт.		50-контактный разъём на плату, наподобии как IDE. Для соединения материнской платы с верхней платой.

XST 2 pin	5шт.		2 штырька на плату для подключений.
XST 3 pin	1шт.		3 штырька на плату для подключений.
XST 4 pin	1шт.		4 штырька на плату в один ряд для подключений.
XST 3+2 pin	1шт.		2 ряда штырьков, в одном 3 штырька, во втором 2 штырька (питание ПЗУ для режима программирования).

Ext ISA		1шт.		ISA разъём. Можно расширенный, можно короткий.
NemoBus		4шт.		Разъём 62 контакта под NEMO Bus.
CR2032 socket	1шт.		Гнездо для установки литиевой батарейки CR2032.

ATX-20Pin	1шт.		Разъём питания ATX на 20 контактов на плату.

Панельки под микросхемы:

DIP-8		1шт.		Под Attiny13A.
DIP-24 широкий	1шт.		Под CMOS часики.
DIP-28 широкий	1шт.		Под ПЗУ 27C512.
DIP-32 узкий	1шт.		Под статическое ОЗУ IS61C1024.
DIP-32 широкий	1шт.		Под ПЗУ W27C1024.
DIP-40 широкий	2шт.		Под Z84 и ВГ93.
SIMM 30pin	1шт.		Под SIMM 30 pin.

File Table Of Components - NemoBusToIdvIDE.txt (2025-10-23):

Резисторы:

МЛТ-0.125:

680 Ом		3шт.
1 кОм		2шт.

Диоды:

1N4148		5шт.

Микросхемы:

КР1533ИД14	1шт.		74ALS139
КР1533ЛА2	1шт.		74ALS30
КР1533ЛА3	1шт.		74ALS00
КР1533ЛЕ4	1шт.		74ALS27
КР1533ЛП8	1шт.		74ALS125
КР1533ТМ2	1шт.		74ALS74

Разъёмы:

Jump 2 pin	1шт.		Обычные 2 штырька на плату под перемычку.

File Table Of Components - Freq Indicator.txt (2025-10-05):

Резисторы:
МЛТ-0.125:

150 Ом			8шт.	Номинал подобран под индикатор синего цвета XR-S3631BR. Под красный индикатор сопротивление должно быть 330 Ом.
510 Ом			2шт.
1 кОм			1шт.
100 кОм			3шт.

Конденсаторы:
Керамические:

0.1 мкф			1шт.

Электролитические:

47 мкф 16в		1шт.

Транзисторы:
Полевые:

BS170			3шт.

Микросхемы:
Цифровые:

ATtiny2313-20PU		1шт.

Индикаторы свтодиодные:

XR-S3631AB		1шт.		AR = красный, AG = зелёный, AB = синий.

Разъёмы:

XST 4 pin		1шт.		Штырьковый рвзъём на 4 штырька в один ряд.
XST 3 pin		1шт.		Штырьковый рвзъём на 3 штырька.
XST 2 pin		2шт.		Штырьковый рвзъём на 2 штырька.

Панельки под микросхемы:

DIP-20			1шт.		Под Attiny2313A.

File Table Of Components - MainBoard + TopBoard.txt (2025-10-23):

Резисторы:

МЛТ-0.125:

1 Ом		1шт.
10 Ом		1шт.
20 Ом		1шт.
68 Ом		4шт.
75 Ом		4шт.
110 Ом		3шт.
120 Ом		1шт.
150 Ом		1шт.
200 Ом		1шт.
220 Ом		3шт.
330 Ом		7шт.
430 Ом		1шт.
470 Ом		6шт.
510 Ом		4шт.
560 Ом		1шт.
620 Ом		1шт.
680 Ом		26шт.
820 Ом		2шт.
1 кОм		33шт.
1.1 кОм		3шт.
1.3 кОм		1шт.
1.5 кОм		1шт.
1.6 кОм		3шт.
1.8 кОм		1шт.
2 кОм		3шт.
2.2 кОм		4шт.
2.4 кОм		1шт.
3 кОм		2шт.
3.6 кОм		1шт.
3.9 кОм		4шт.
4.7 кОм		4шт.
6.8 кОм		25шт.
7.5 кОм		1шт.
10 кОм		37шт.
16 кОм		1шт.
20 кОм		1шт.
22 кОм		9шт.
24 кОм		10шт.
27 кОм		3шт.
30 кОм		1шт.
47 кОм		8шт.
100 кОм		5шт.
2 МОм		1шт.
4.7 МОм		2шт.

Подстроечные:

1 кОм		3шт.
2.2 кОм		1шт.

Конденсаторы:

Керамические:

10 пф		1шт.
20 пф		2шт.
27 пф		1шт.
33 пф		6шт.
47 пф		1шт.
100 пф		5шт.
200 пф		1шт.
300 пф		3шт.
470 пф		1шт.
1 нф		1шт.
6.8 нф		1шт.
10 нф		4шт.
22 нф		1шт.
0.1 мкф		94шт.
0.22 мкф	2шт.

Электролитические:

1 мкф 16в	1шт.
4.7 мкф 16в	1шт.
10 мкф 16в	22шт.
47 мкф 16в	2шт.
100 мкф 16в	3шт.
220 мкф 10в	4шт.
470 мкф 10в	1шт.
1000 мкф 10в	2шт.
2200 мкф 10в	1шт.

Кварцевые резонаторы:

32.768 КГц	1шт.
3.58 МГц (NTSC)	1шт.
4.43 МГц (PAL)	1шт.
8 МГц		1шт.
14 МГц		1шт.
20 МГц		2шт.

Диоды:

1N4148		29шт.
1N5817		7шт.

Стабилитрон:
5.1V		1шт.

Транзисторы:

Биполярные:

КТ315Б		2шт.
КТ3102		4шт.

Полевые:

BS170		2шт.			Под CXA1645 нужно 2 шт, под CXA2075 нужно 1 шт.
BS250		1шт.			Ставится только если установлена микросхема кодера PAL CXA2075.

Микросхемы:

Аналоговые:

К554СА3			1шт.
CXA1645 или CXA2075	1шт.
LM324			1шт.
LM358			3шт.
LM7905 (TO220)		1шт.
MAX660			1шт.
MAX3232			1шт.
TLC7528			2шт.

Цифровые:

КР1531АП5		1шт.		74F244
КР1531АП6		2шт.		74F245
КР1531ИД7		2шт.		74F138
КР1531ИД14		1шт.		74F139
КР1531ИЕ17		2шт.		74F169
КР1531ИР22		2шт.		74F373
КР1531ИР23		2шт.		74F374
КР1531КП2		2шт.		74F153
КР1531КП7		3шт.		74F151
КР1531КП11		2шт.		74F257			Mainboard: DD82, DD83
КР1531КП11 / КП16	4шт.		74F257 / 74F157		Mainboard: DD45, DD46, DD104, DD105
КР1531КП12		10шт.		74F253
КР1531ЛА1		1шт.		74F20
КР1531ЛА3		3шт.		74F00
КР1531ЛА4		1шт.		74F10
КР1531ЛЕ1		2шт.		74F02
КР1531ЛЕ4		1шт.		74F27
КР1531ЛИ1		5шт.		74F08
КР1531ЛИ3		2шт.		74F11
КР1531ЛЛ1		9шт.		74F32
КР1531ЛН1		3шт.		74F04
КР1531ЛП5		3шт.		74F86
КР1531ТМ2		4шт.		74F74
КР1531ТМ8		1шт.		74F175

КР1533АГ3		1шт.		74ALS123
КР1533АП5		2шт.		74ALS244
КР1533ИД7		5шт.		74ALS138
КР1533ИЕ5		1шт.		74ALS93
КР1533ИЕ10		1шт.		74ALS161
КР1533ИЕ19		2шт.		74ALS393
КР1533ИР9		1шт.		74ALS165
КР1533ИР22		3шт.		74ALS373
КР1533ИР23		4шт.		74ALS374
КР1533ИР35		4шт.		74ALS273
КР1533КП2		2шт.		74ALS153
КР1533КП11		2шт.		74ALS257
КР1533ЛА2		7шт.		74ALS30
КР1533ЛА3		2шт.		74ALS00
КР1533ЛА4		1шт.		74ALS10
КР1533ЛЕ1		5шт.		74ALS02
КР1533ЛИ1		11шт.		74ALS08
КР1533ЛИ3		2шт.		74ALS11
КР1533ЛИ6		1шт.		74ALS21
КР1533ЛЛ1		10шт.		74ALS32
КР1533ЛН1		6шт.		74ALS04
КР1533ЛП8		1шт.		74ALS125
КР1533ТМ2		9шт.		74ALS74
КР1533ТМ8		3шт.		74ALS175
КР1533ТМ9		4шт.		74ALS174

К555ИР16		1шт.		74LS295
К555ИР23		1шт.		74LS374
К555ЛН2			1шт.		74LS05
К555ТМ2			1шт.		74LS74
К555ТМ9			1шт.		74LS174

74HCT00			1шт.
MC14069			1шт.

К155РУ2			3шт.		К531РУ8, К531РУ9, 7489, 74LS89, 74ALS89, 74LS189, 74ALS189, 74S189, 74LS289, 74ALS289, 74S289
27C512			1шт.
W27C010			1шт.
IS61C1024		1шт.
SIMM 30PIN 4MB		1шт.
HM6818A			1шт.
ATtiny13A		1шт.
ATtiny2313-20PU		1шт.
ATmega48PA-PU		1шт.
Z84C0020PEC		1шт.
AY-3-8910 / AY-3-8912	1шт.		AY-3-8910, AY-3-8912, Yamaha-2149F, либо подключение TurboSound, TurboSound-FM.
КР1818ВГ93		1шт.

Разъёмы:

Jump 2 pin		7шт.		Обычные 2 штырька на плату под перемычку.
Jump 3 pin		14шт.		Обычные 3 штырька на плату под перемычку на 2 положения.

BH-26			1шт.		Разъём на плату, аналогичный как IDE, но на 26 контактов, либо просто 2 ряда штырьков по 13 контактов. Для подключения планки LPT.
BH-34			1шт.		Разъём на плату для подключения дисковода FDD.
BH-40			1шт.		Разъём на плату для подключения HDD.
BH-50			2шт.		50-контактный разъём на плату, наподобии как IDE. Для соединения материнской платы с верхней платой.

XST 2 pin		5шт.		2 штырька на плату для подключений.
XST 3 pin		1шт.		3 штырька на плату для подключений.
XST 4 pin		5шт.		4 штырька на плату в один ряд для подключений. Аудио входы и выход на плате, подключение светодиода и кнопки питания.
XST 3+2 pin		1шт.		2 ряда штырьков, в одном 3 штырька, во втором 2 штырька (питание ПЗУ для режима программирования).
XST 5+4 pin (RS232)	1шт.		Штырьковый разъём на плату в 2 ряда 5 и 4 штырька. Для подключения планки RS-232.

DA15 Female		1шт.		15-контактный угловой разъём на плату, как на звуковых картах ПК под джойстик. Механическая клавиатура.
DE9 Female		1шт.		9-контактный угловой разъём на плату, как в ПК ставили под COM-1. Джойстик.
DE15 Female (монитор)	1шт.		3-рядный угловой VGA разъём на плату. Монитор.
Mini-DIN-6pin x2	1шт.		Двойной PS/2, какие ставят на материнские платы ПК. Клавиатура и мышь.
Mini-DIN-4pin		1шт.		В металлическом корпусе под плату. S-Video.
RCA-313			1шт.		Тройной RCA башней. Аудио и видео выходы.

Ext ISA			1шт.		ISA разъём. Можно расширенный, можно короткий.
NemoBus			4шт.		Разъём 62 контакта под NEMO Bus.
CR2032 socket		1шт.		Гнездо для установки литиевой батарейки CR2032.

ATX-20Pin		1шт.		Разъём питания ATX на 20 контактов на плату.
Molex 4pin Male		1шт.		Прямой разъём Molex на плату для подключения БП.

Панельки под микросхемы:

DIP-8			1шт.		Под Attiny13A.
DIP-16			3шт.		Под К155РУ2 в регистр палитры.
DIP-20			3шт.		Под Attiny2313A и под ЦАПы TLC7528.
DIP-24 широкий		1шт.		Под CMOS часики.
DIP-24 под CXA1645	1шт.		Придётся переделывать из DIP-24 широкой, - нужна средняя ширина между DIP узкий и широкий.
DIP-28 узкий		1шт.		Под Atmega48PA-PU.
DIP-28 широкий		2шт.		Под ПЗУ 27C512, AY-3-8912.
DIP-32 узкий		1шт.		Под статическое ОЗУ IS61C1024.
DIP-32 широкий		1шт.		Под ПЗУ W27C1024.
DIP-40 широкий		3шт.		Под Z84, AY-3-8910 и ВГ93.
SIMM 30pin		1шт.		Под SIMM 30 pin.

Дополнительно:

Разъём IDC-50		2шт.		Ответный разъём на 50 контактов под шлейф, вставляется в гнездо BH-50.
Шлейф 50 жил под IDC-50	30см		Точную длину лучше отмерять по месту при сборке. Для соединения материнской платы с верхней.
Латунные стойки 6мм	10шт.		Крепление материнской платы в корпус.
Латунные стойки 40мм	4шт.		Для установки верхней платы на материнскую.

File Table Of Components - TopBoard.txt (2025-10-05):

Резисторы:

МЛТ-0.125:

1 Ом		1шт.
10 Ом		1шт.
20 Ом		1шт.
68 Ом		4шт.
75 Ом		4шт.
110 Ом		3шт.
120 Ом		1шт.
150 Ом		1шт.
200 Ом		1шт.
220 Ом		3шт.
470 Ом		2шт.
510 Ом		3шт.
620 Ом		1шт.
680 Ом		4шт.
820 Ом		2шт.
1 кОм		24шт.
1.1 кОм		3шт.
1.3 кОм		1шт.
1.5 кОм		1шт.
1.6 кОм		3шт.
1.8 кОм		1шт.
2 кОм		3шт.
2.4 кОм		1шт.
3.6 кОм		1шт.
3.9 кОм		4шт.
4.7 кОм		4шт.
6.8 кОм		9шт.
7.5 кОм		1шт.
10 кОм		11шт.
16 кОм		1шт.
20 кОм		1шт.
22 кОм		6шт.
24 кОм		10шт.
27 кОм		3шт.
30 кОм		1шт.
47 кОм		8шт.
100 кОм		5шт.
4.7 МОм		2шт.

Подстроечные:

1 кОм		3шт.
2.2 кОм		1шт.

Конденсаторы:

Керамические:

10 пф		1шт.
20 пф		2шт.
33 пф		5шт.
47 пф		1шт.
100 пф		4шт.
470 пф		1шт.
10 нф		3шт.
22 нф		1шт.
0.1 мкф		29шт.

Электролитические:

1 мкф 16в	1шт.
4.7 мкф 16в	1шт.
10 мкф 16в	20шт.
47 мкф 16в	2шт.
100 мкф 16в	1шт.
220 мкф 10в	3шт.
470 мкф 10в	1шт.

Дроссели:

100 мкГн	1шт.
150 мкГн	1шт.

Кварцевые резонаторы:

3.58 МГц (NTSC)	1шт.
4.43 МГц (PAL)	1шт.
20 МГц		2шт.

Диоды:

1N4148		21шт.

Транзисторы:

Биполярные:

КТ3102		4шт.

Полевые:

BS170		2шт.			Под CXA1645 нужно 2 шт, под CXA2075 нужно 1 шт.
BS250		1шт.			Ставится только если установлена микросхема кодера PAL CXA2075.

Микросхемы:

Аналоговые:

К554СА3			1шт.
CXA1645 или CXA2075	1шт.
LM324			1шт.
LM358			3шт.
MAX660			1шт.
MAX3232			1шт.
TLC7528			2шт.

Цифровые:

КР1533АП5		2шт.		74ALS244
КР1533ИД7		2шт.		74ALS138
КР1533КП11		2шт.		74ALS257
КР1533ЛА2		1шт.		74ALS30
КР1533ЛИ1		4шт.		74ALS08
КР1533ЛИ3		1шт.		74ALS11
КР1533ЛЛ1		1шт.		74ALS32
КР1533ЛН1		1шт.		74ALS04

74HCT00			1шт.

К155РУ2			3шт.		К531РУ8, К531РУ9, 7489, 74LS89, 74ALS89, 74LS189, 74ALS189, 74S189, 74LS289, 74ALS289, 74S289
ATmega48PA-PU		1шт.
ATtiny2313-20PU		1шт.
AY-3-8910 / AY-3-8912	1шт.		AY-3-8910, AY-3-8912, Yamaha-2149F, либо подключение TurboSound, TurboSound-FM.

Разъёмы:

Jump 2 pin		2шт.		Обычные 2 штырька на плату под перемычку.
Jump 3 pin		4шт.		Обычные 3 штырька на плату под перемычку на 2 положения.

BH-50			1шт.		50-контактный разъём на плату, наподобии как IDE. Для соединения материнской платы с верхней платой.

XST 4 pin		4шт.		Штырьковый рвзъём на 4 штырька в один ряд. Аудио входы и выход на плате.
XST 5+4 pin (RS232)	1шт.		Штырьковый разъём на плату в 2 ряда 5 и 4 штырька. Для подключения планки RS-232.

DA15 Female		1шт.		15-контактный угловой разъём на плату, как на звуковых картах ПК под джойстик. Механическая клавиатура.
DE9 Female		1шт.		9-контактный угловой разъём на плату, как в ПК ставили под COM-1. Джойстик.
DE15 Female (монитор)	1шт.		3-рядный угловой VGA разъём на плату. Монитор.
Mini-DIN-6pin x2	1шт.		Двойной PS/2, какие ставят на материнские платы ПК. Клавиатура и мышь.
Mini-DIN-4pin		1шт.		В металлическом корпусе под плату. S-Video.
RCA-313			1шт.		Тройной RCA башней. Аудио и видео выходы.

Molex 4pin Male		1шт.		Прямой разъём Molex на плату для подключения БП.

Панельки под микросхемы:

DIP-16			3шт.		Под К155РУ2 в регистр палитры.
DIP-20			3шт.		Под Attiny2313A и под ЦАПы TLC7528.
DIP-24 под CXA1645	1шт.		Придётся переделывать из DIP-24 широкой, - нужна средняя ширина между DIP узкий и широкий.
DIP-28 узкий		1шт.		Под Atmega48PA-PU.
DIP-28 широкий		1шт.		Под AY-3-8912.
DIP-40 широкий		1шт.		Под AY-3-8910.

Дополнительно:

Разъём IDC-50		2шт.		Ответный разъём на 50 контактов под шлейф, вставляется в гнездо BH-50.
Шлейф 50 жил под IDC-50	30см		Точную длину лучше отмерять по месту при сборке. Для соединения материнской платы с верхней.
Латунные стойки 40мм	4шт.		Для установки верхней платы на материнскую.

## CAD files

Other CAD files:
Firmwares/Freq Indicator/src/FreqInd.obj

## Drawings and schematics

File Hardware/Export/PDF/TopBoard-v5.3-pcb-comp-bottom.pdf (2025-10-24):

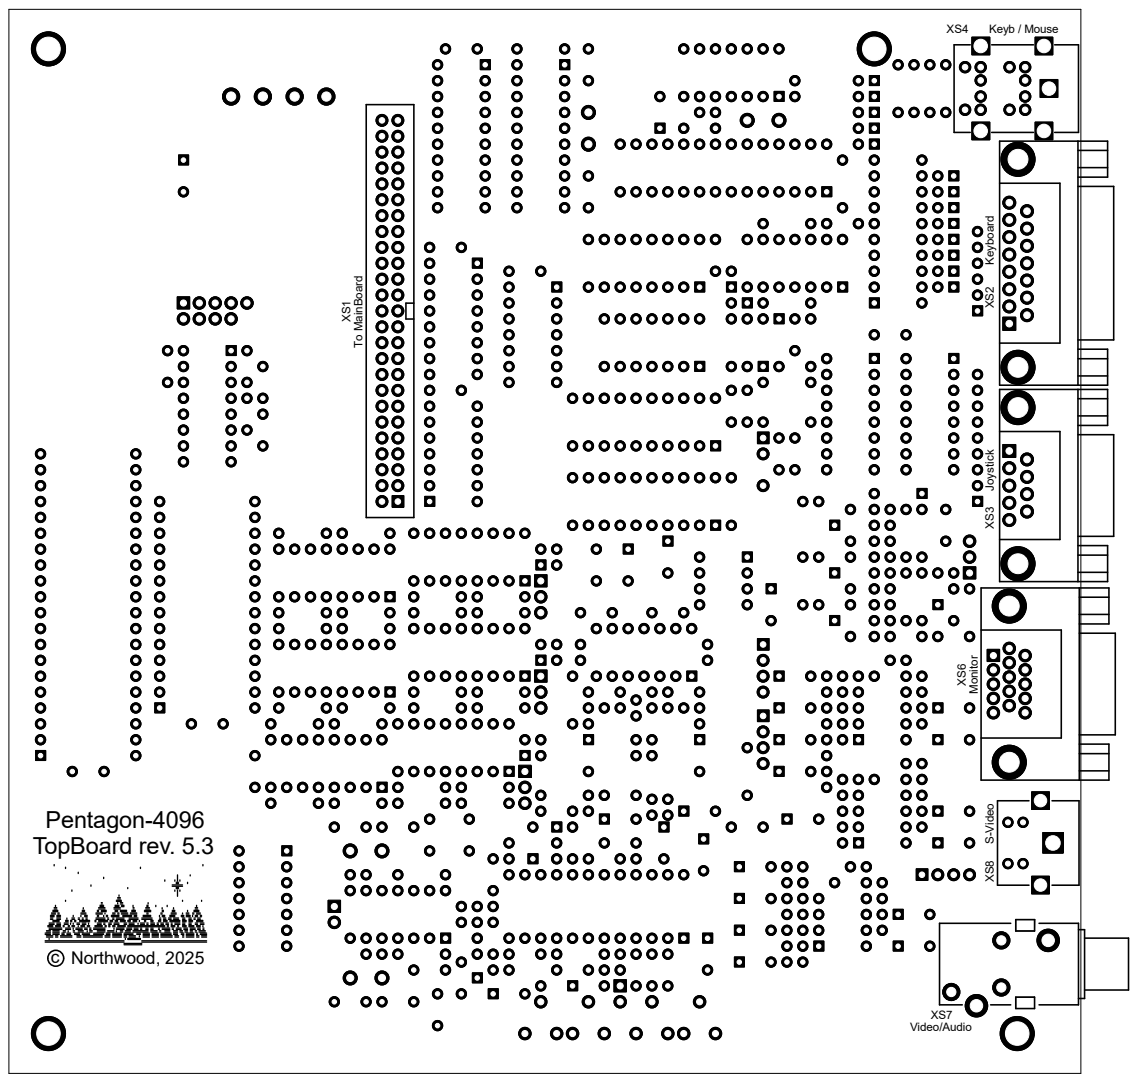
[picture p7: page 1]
c Northwood, 2025; Pentagon-4096 TopBoard rev. 5.3; XS8 S-Video; Monitor; XS3 Joystick; Keyb / Mouse XS² Keyboard; To MainBoard; XS7 Video/Audio

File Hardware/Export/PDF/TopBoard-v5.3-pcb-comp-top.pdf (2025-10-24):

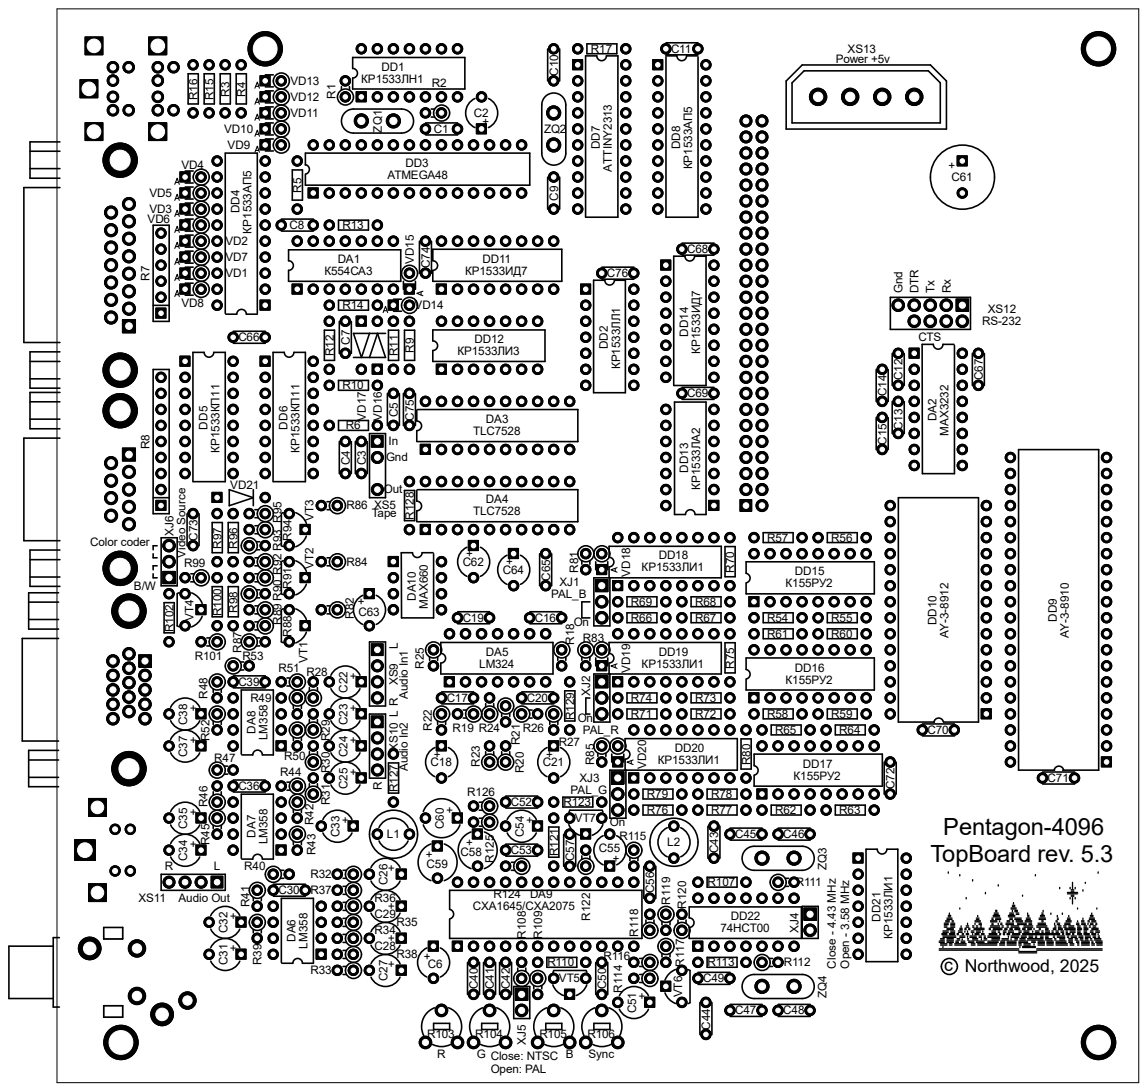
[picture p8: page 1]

C30 R37 DA⁶ LM³⁵⁸ R28 R³⁰ R³¹

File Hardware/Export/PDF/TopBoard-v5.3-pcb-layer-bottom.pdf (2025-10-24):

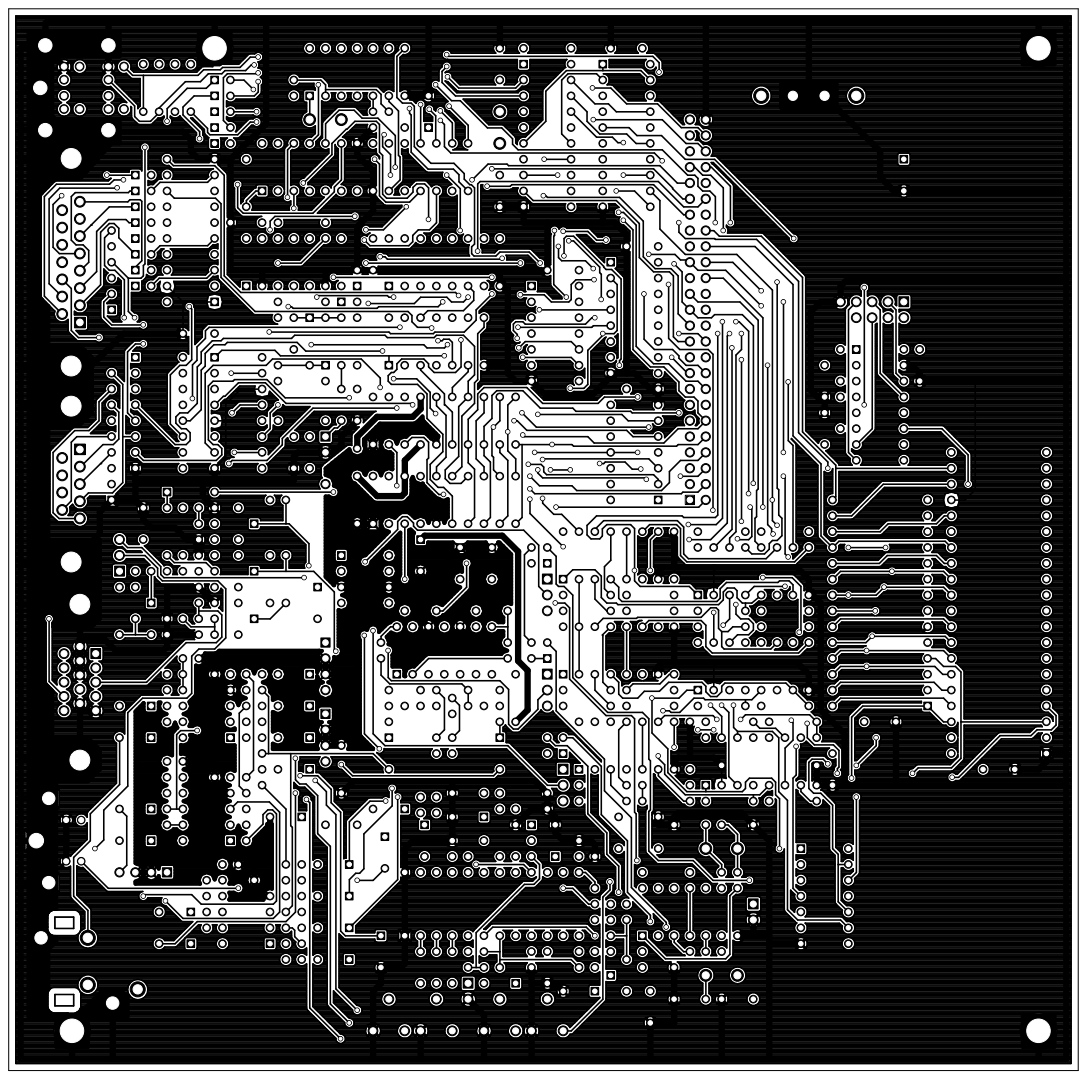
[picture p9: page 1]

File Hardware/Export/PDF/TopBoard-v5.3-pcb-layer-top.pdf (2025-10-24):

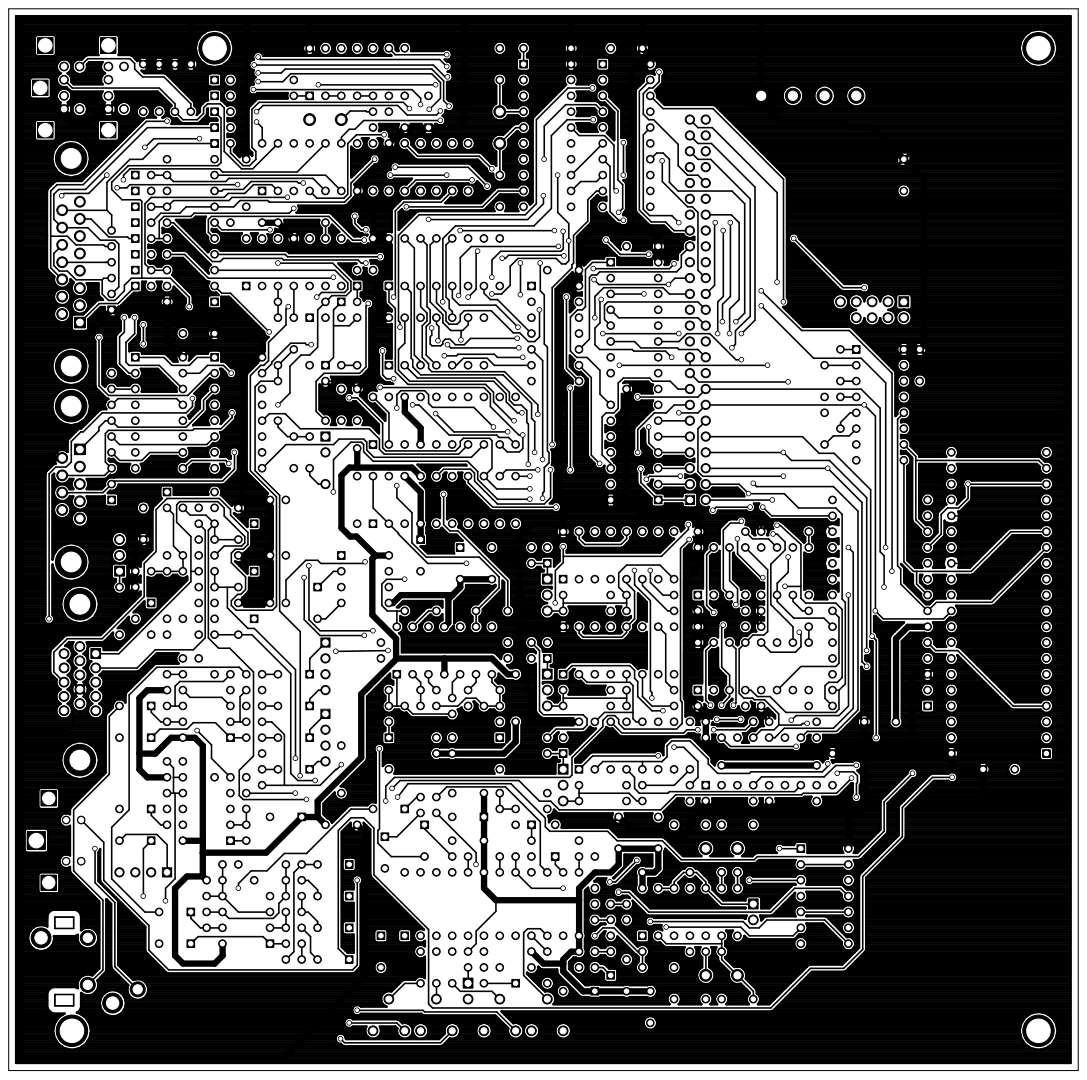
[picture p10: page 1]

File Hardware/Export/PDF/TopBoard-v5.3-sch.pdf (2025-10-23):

MS

RG

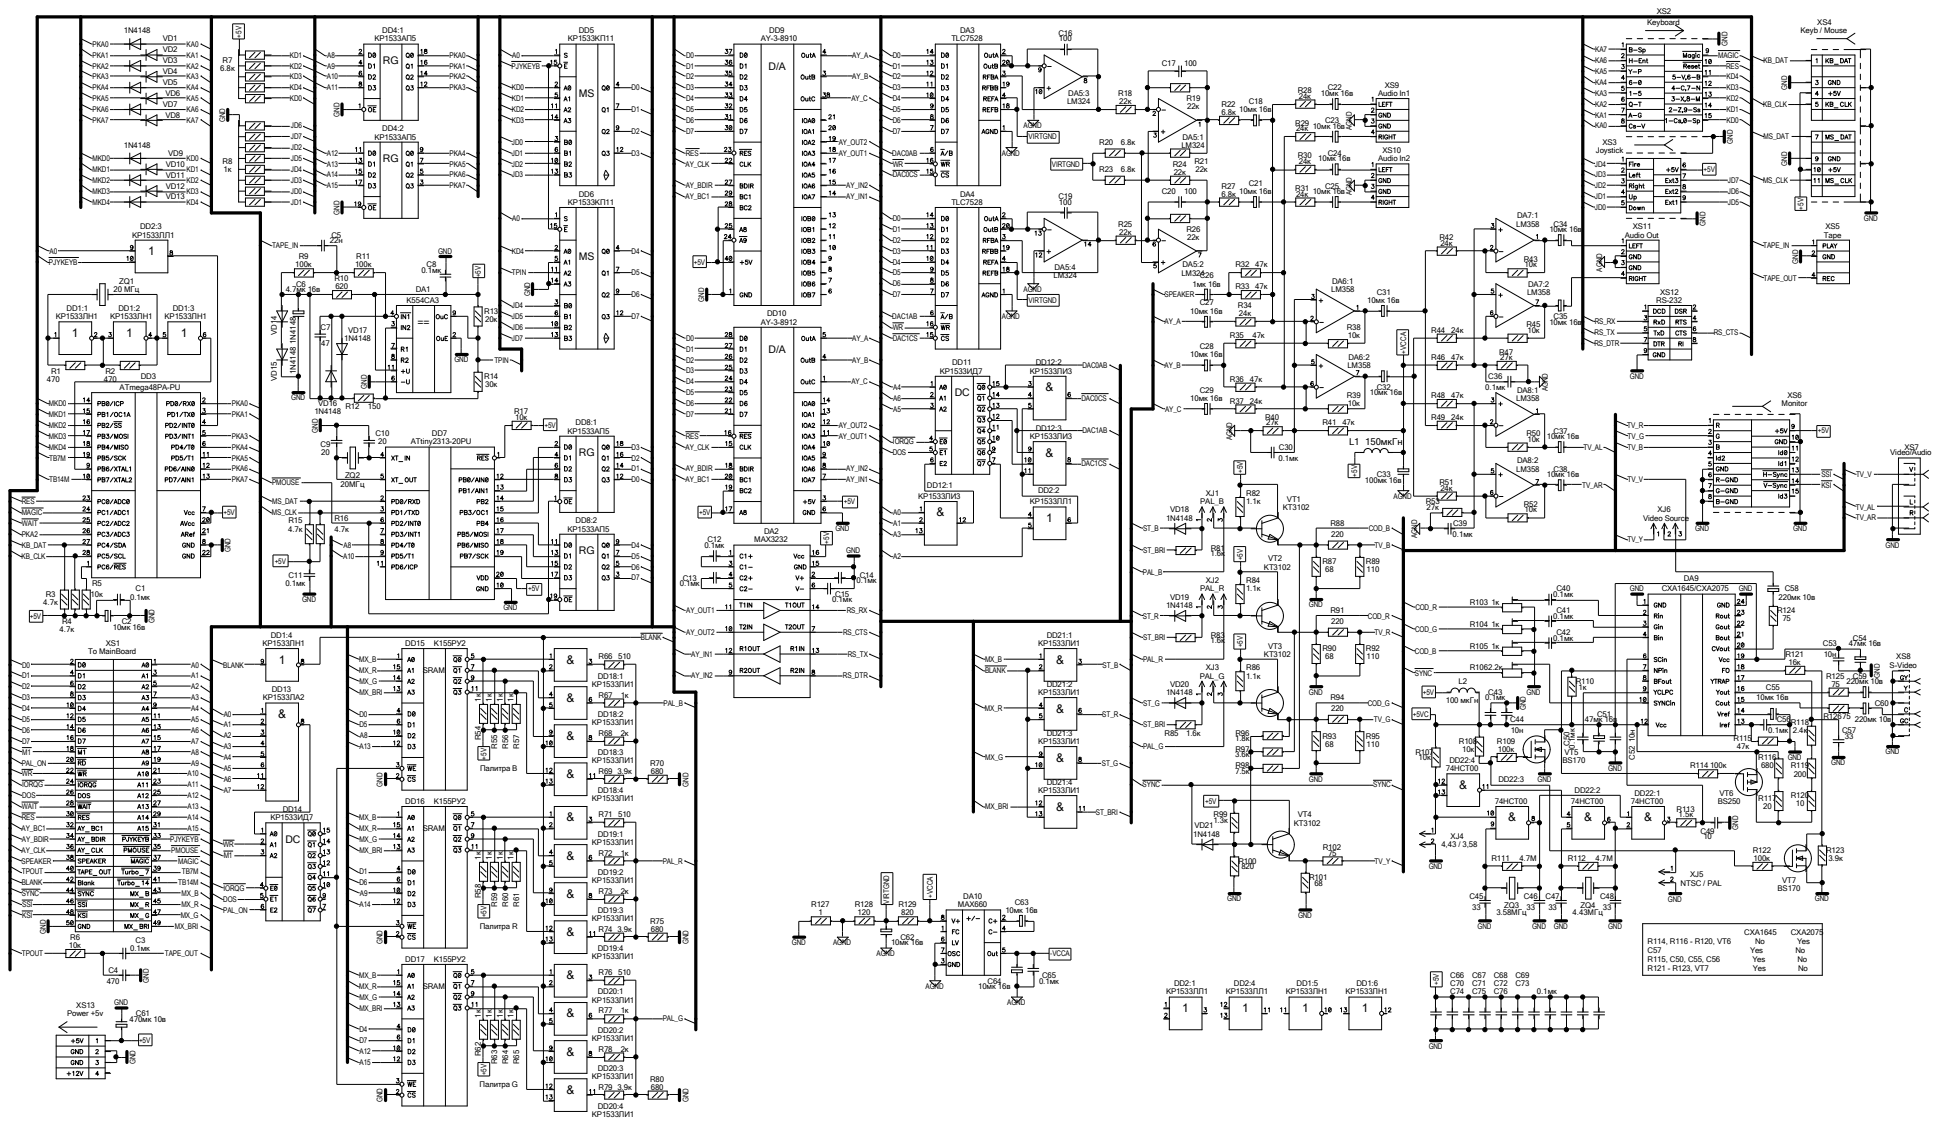
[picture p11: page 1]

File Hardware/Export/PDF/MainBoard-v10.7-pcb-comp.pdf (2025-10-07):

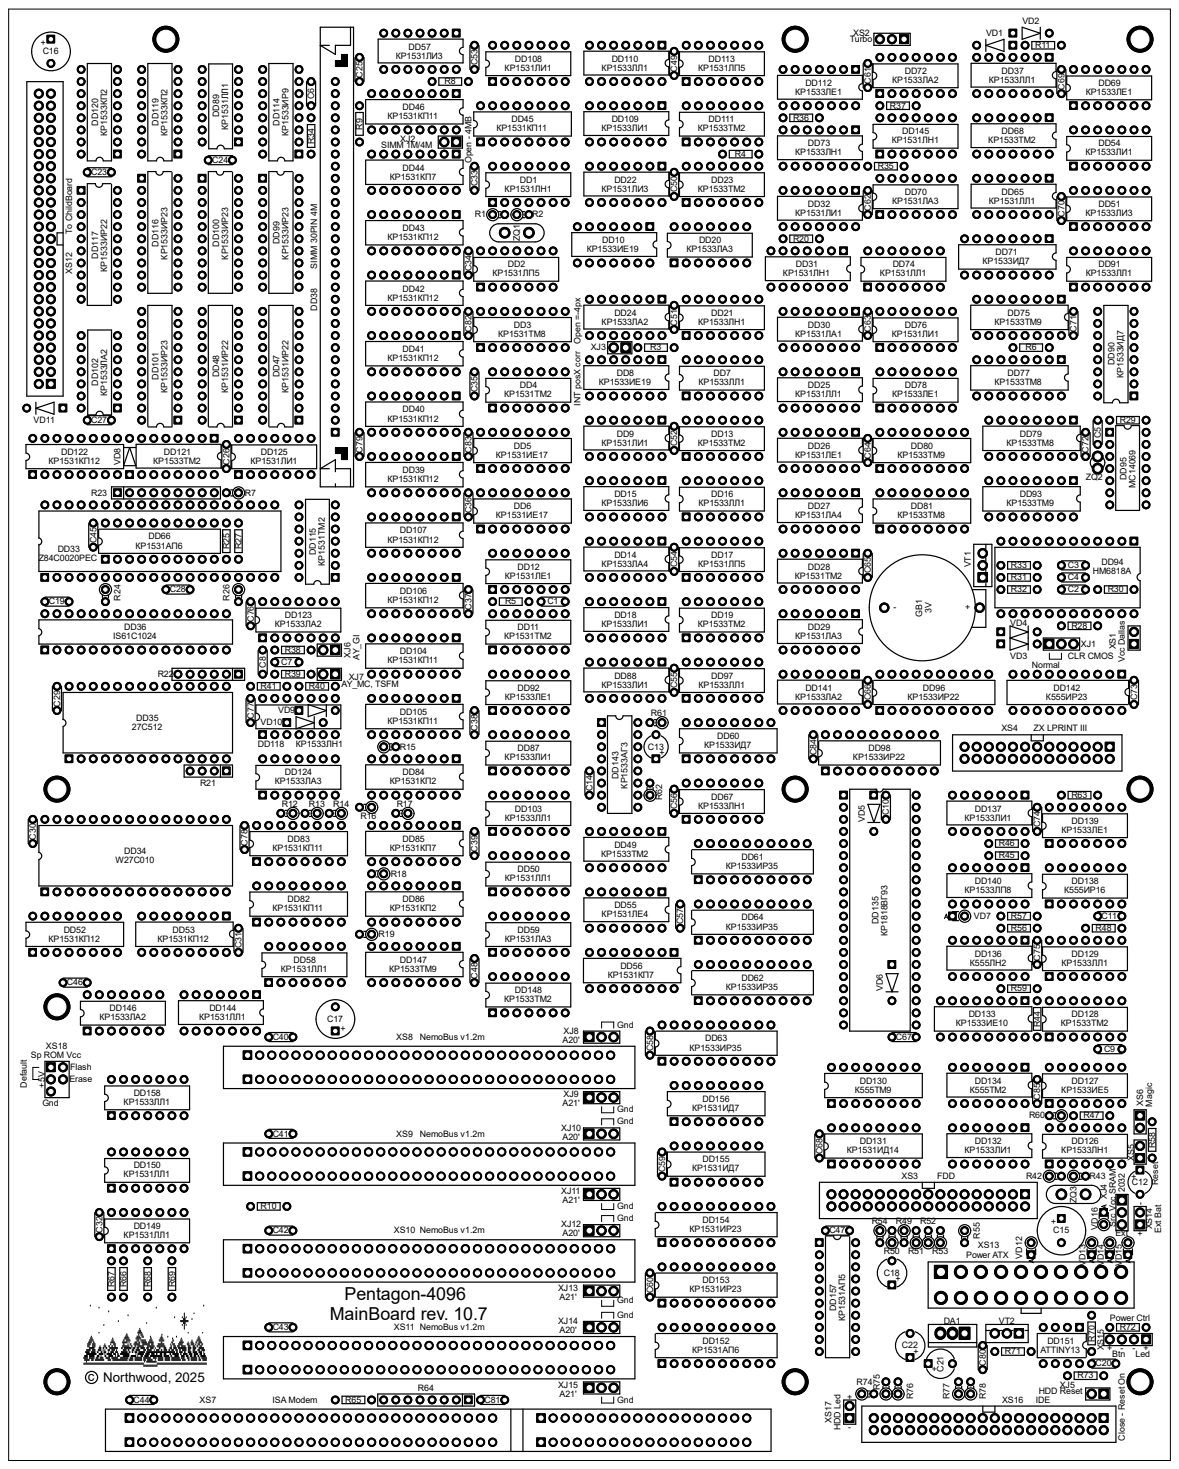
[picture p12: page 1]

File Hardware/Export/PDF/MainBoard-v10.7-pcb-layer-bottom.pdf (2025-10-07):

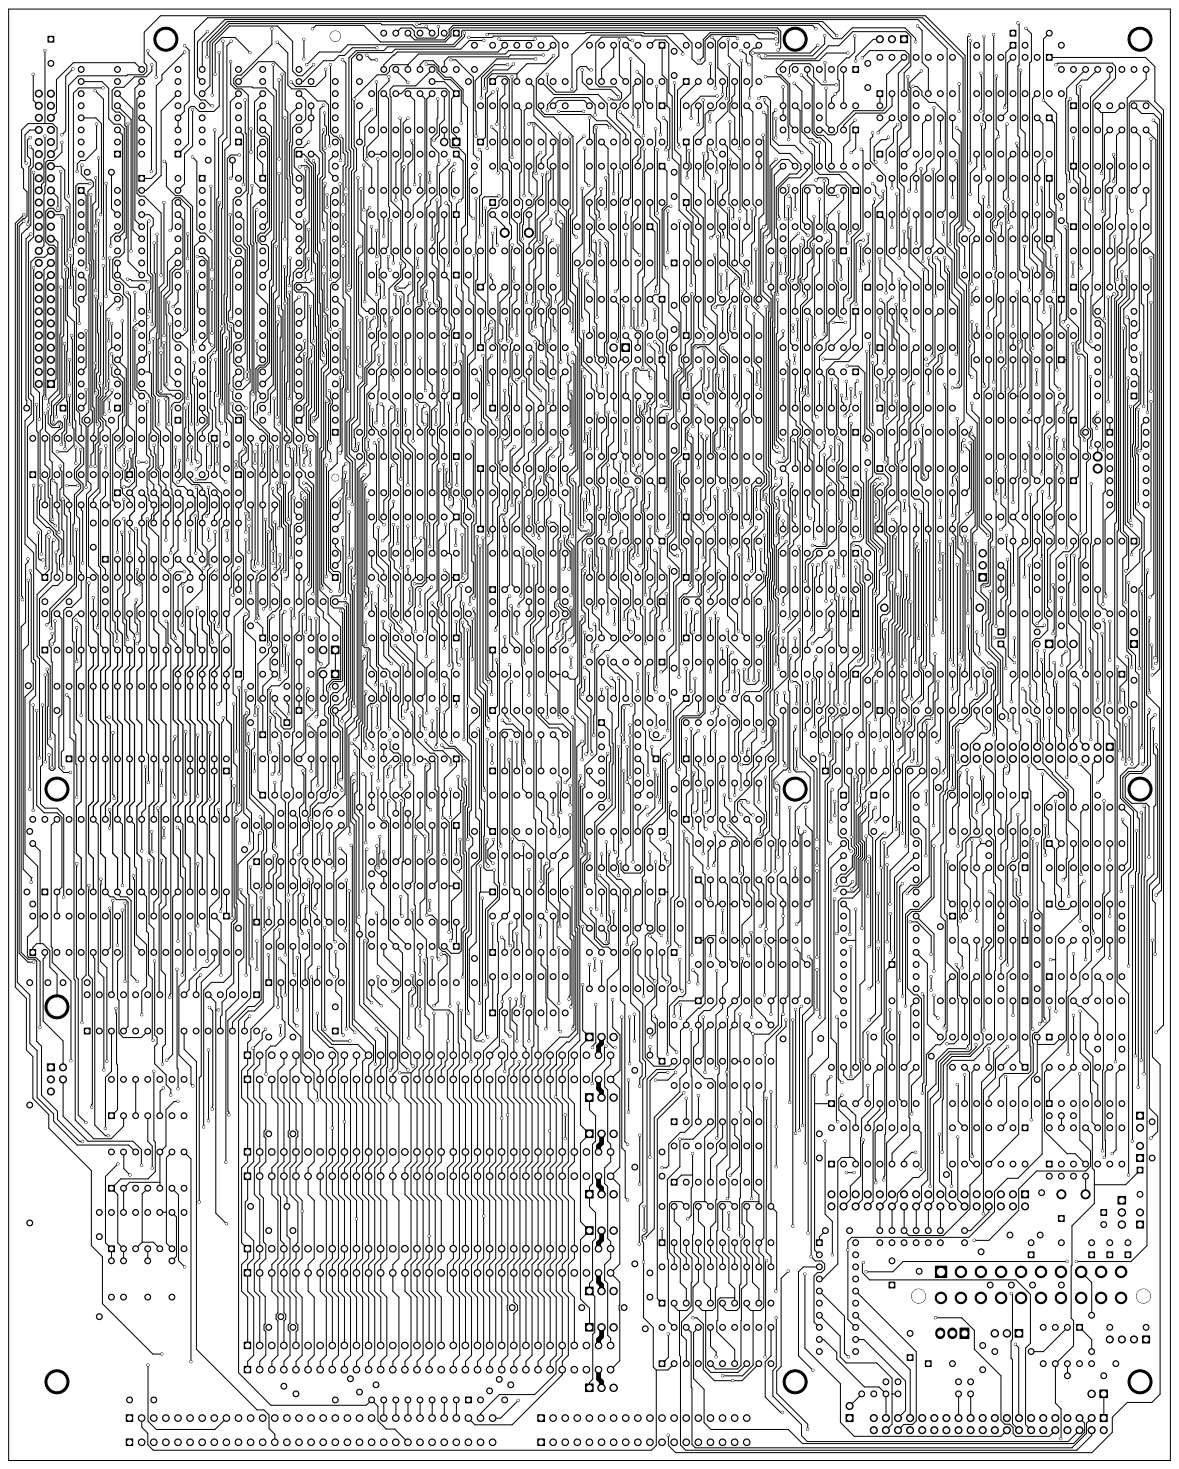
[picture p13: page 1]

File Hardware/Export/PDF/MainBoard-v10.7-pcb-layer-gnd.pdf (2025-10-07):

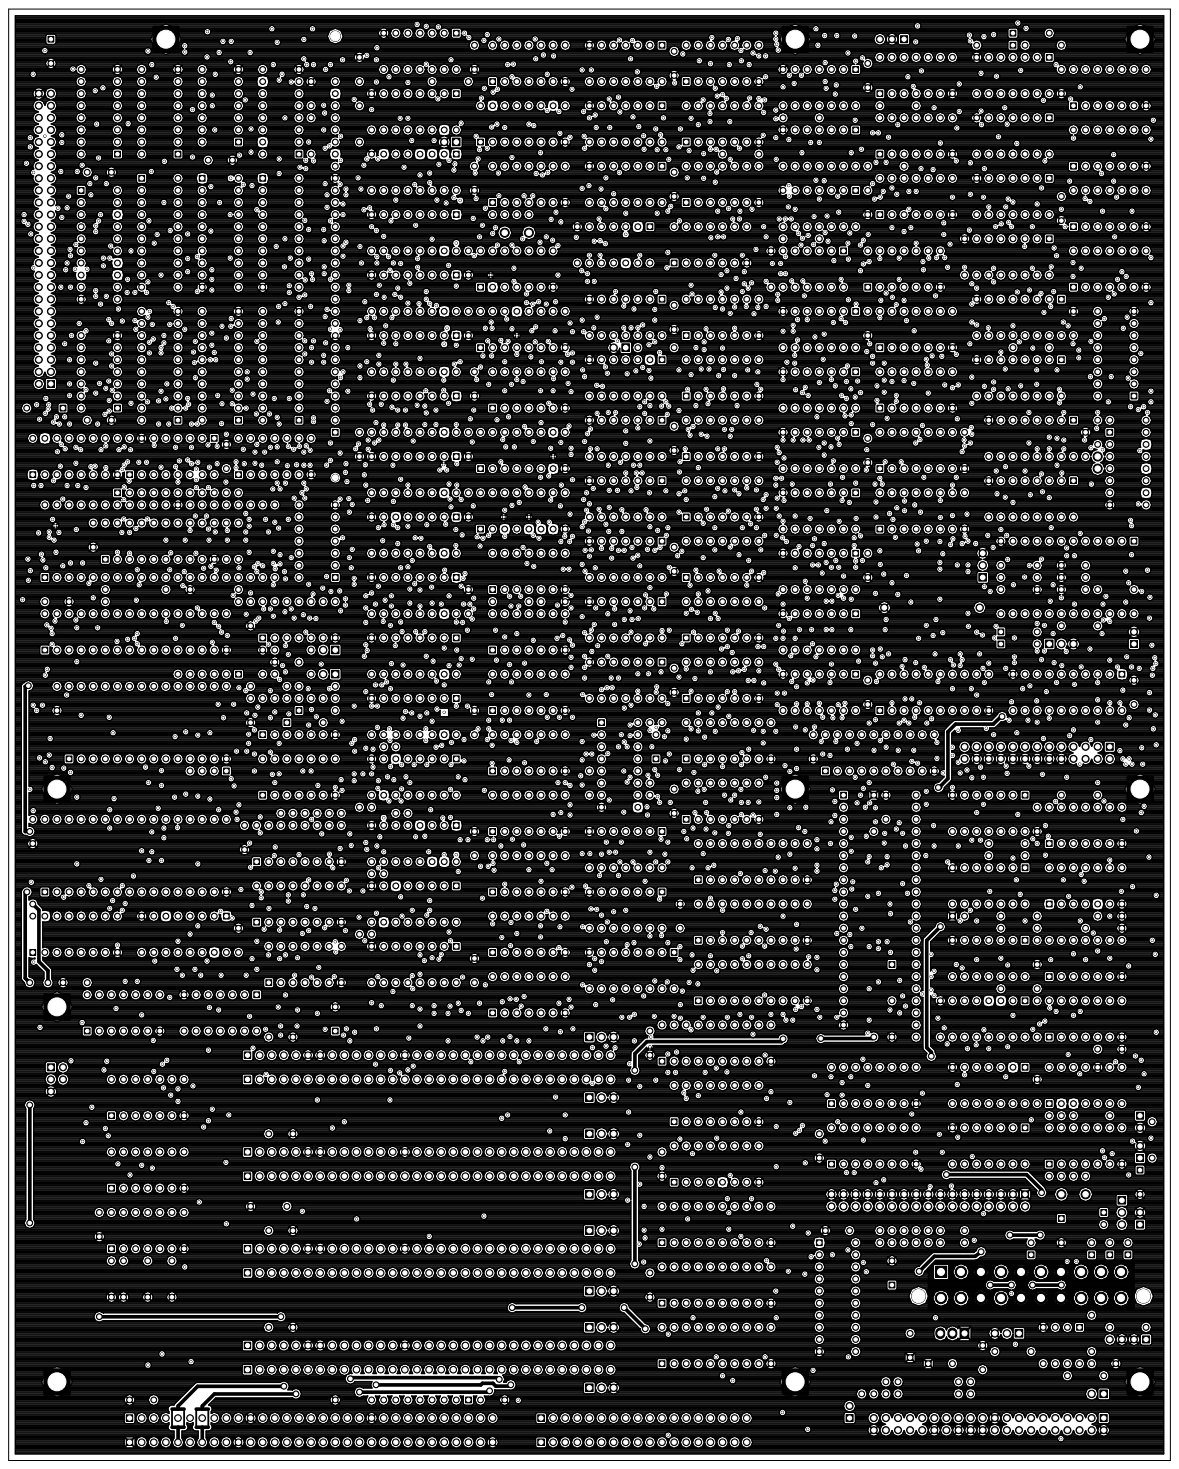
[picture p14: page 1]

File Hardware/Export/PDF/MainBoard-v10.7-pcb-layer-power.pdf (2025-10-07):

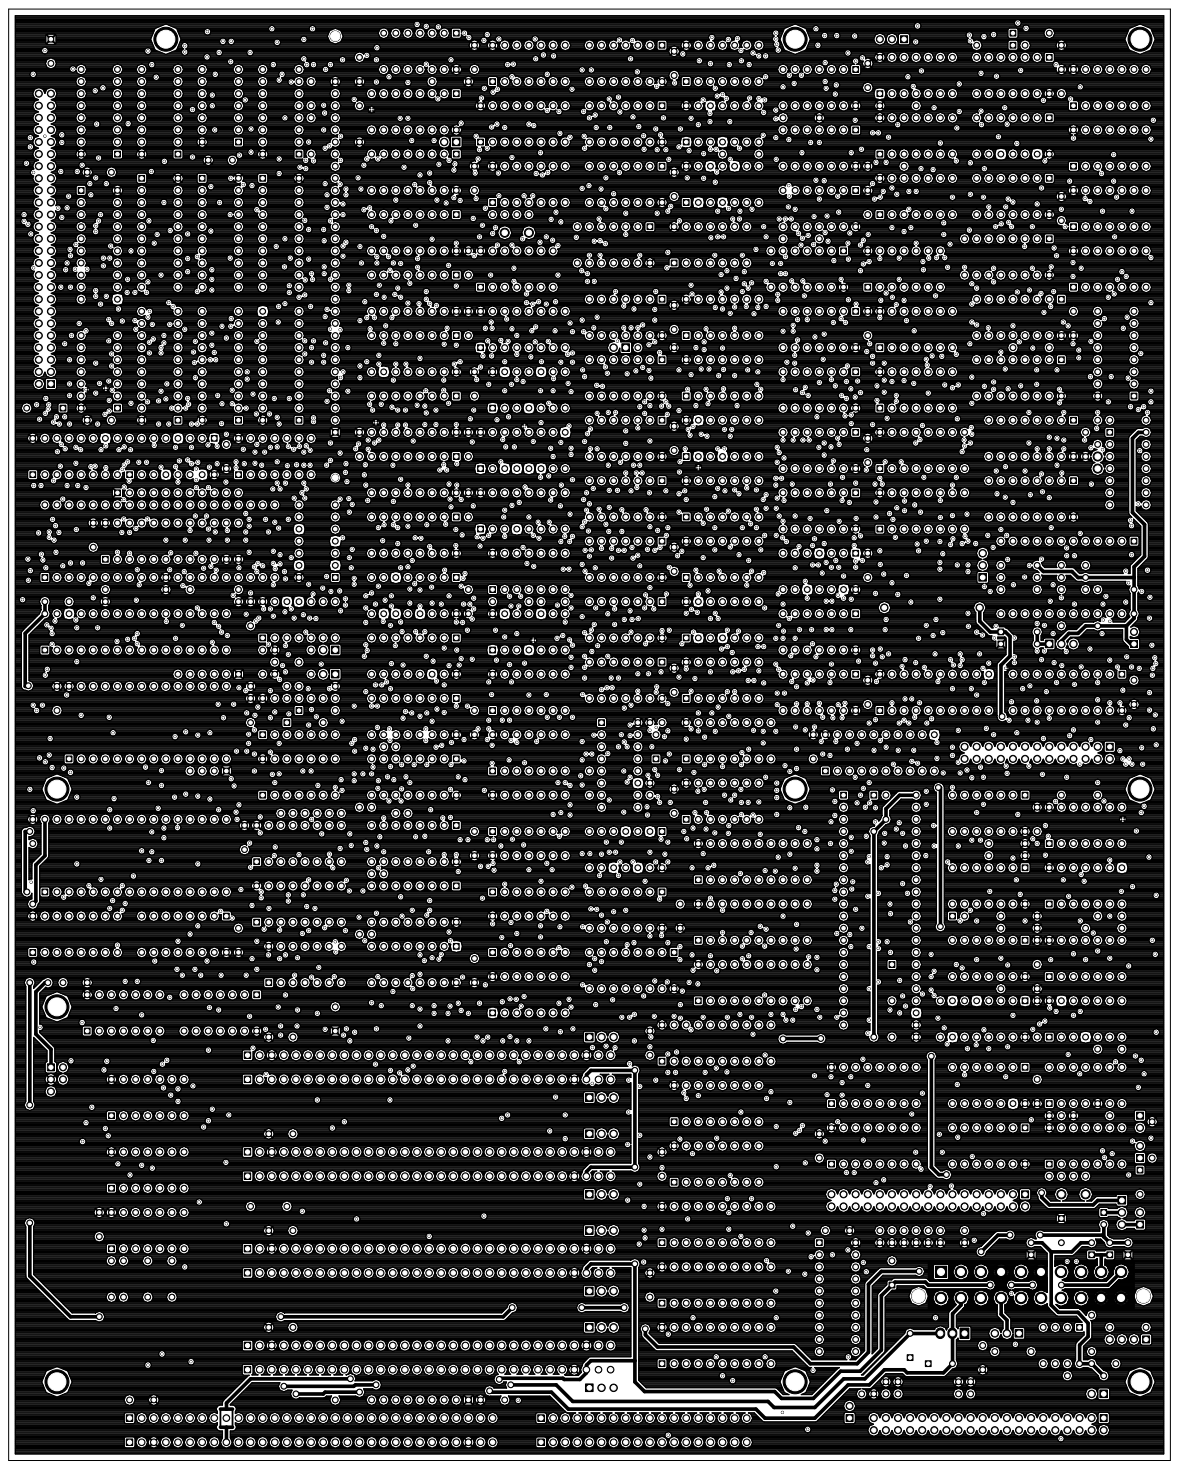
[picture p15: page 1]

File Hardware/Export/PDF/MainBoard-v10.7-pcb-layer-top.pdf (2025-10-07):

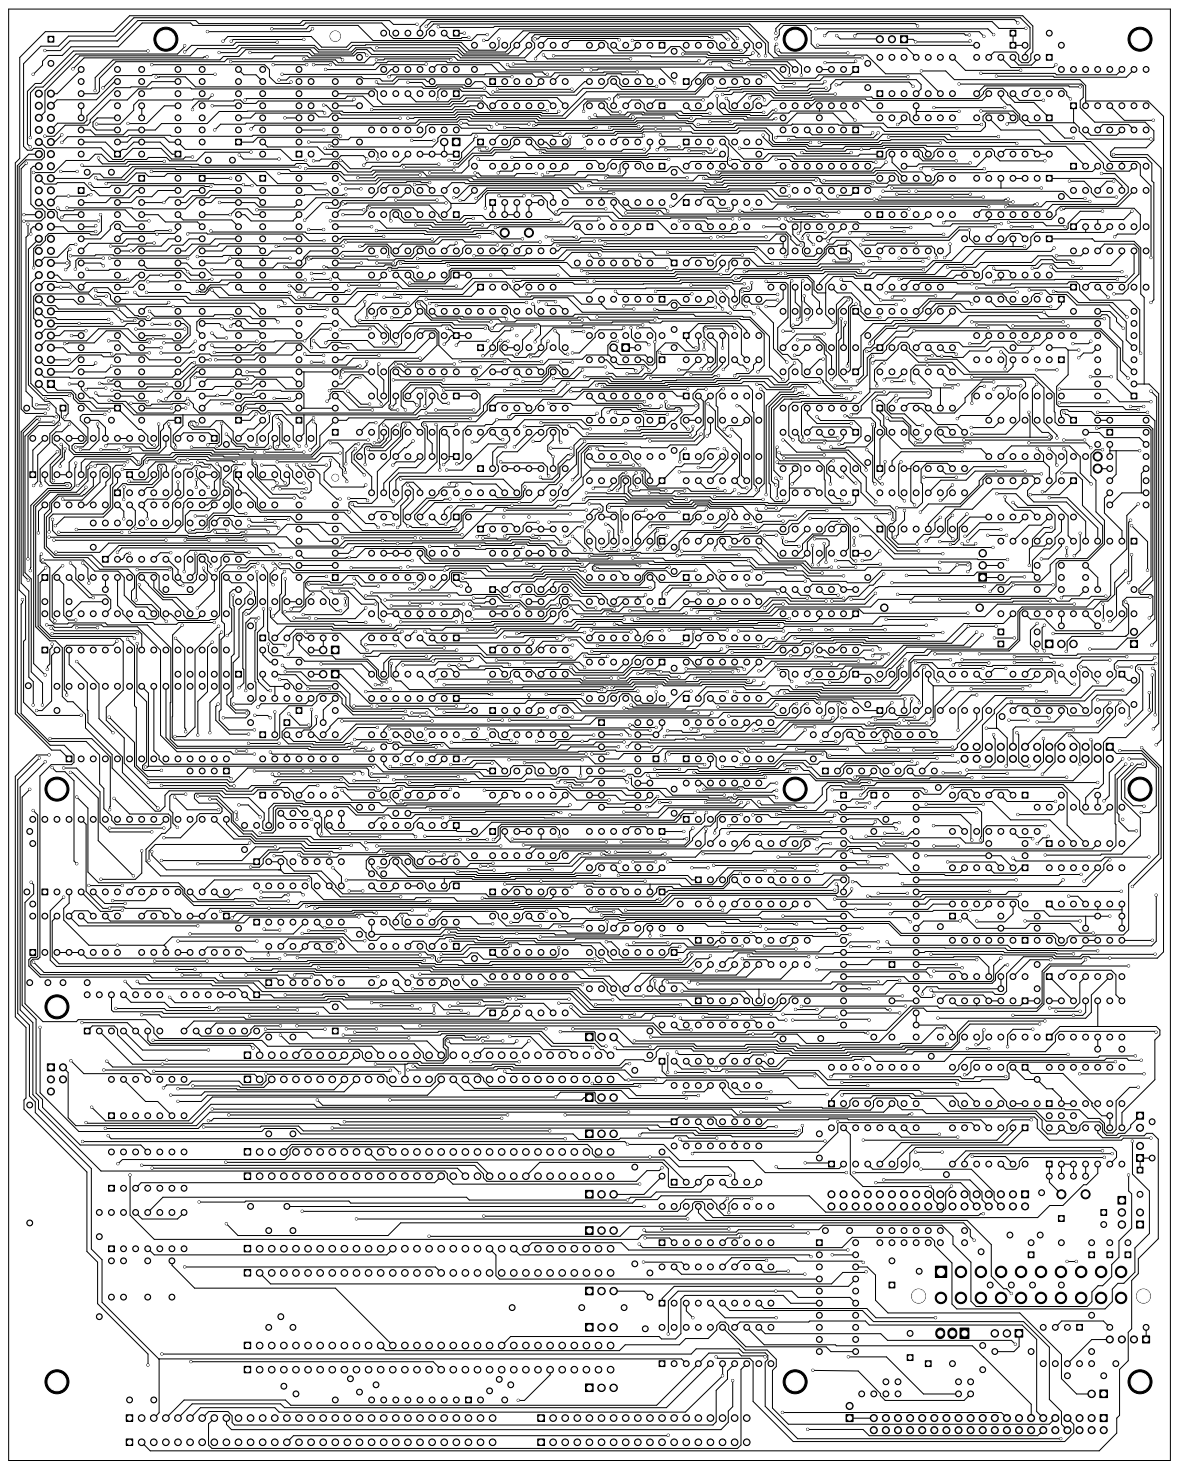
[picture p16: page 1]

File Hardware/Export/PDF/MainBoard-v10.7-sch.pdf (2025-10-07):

## A8⁺⁵V A4

# MA0GND

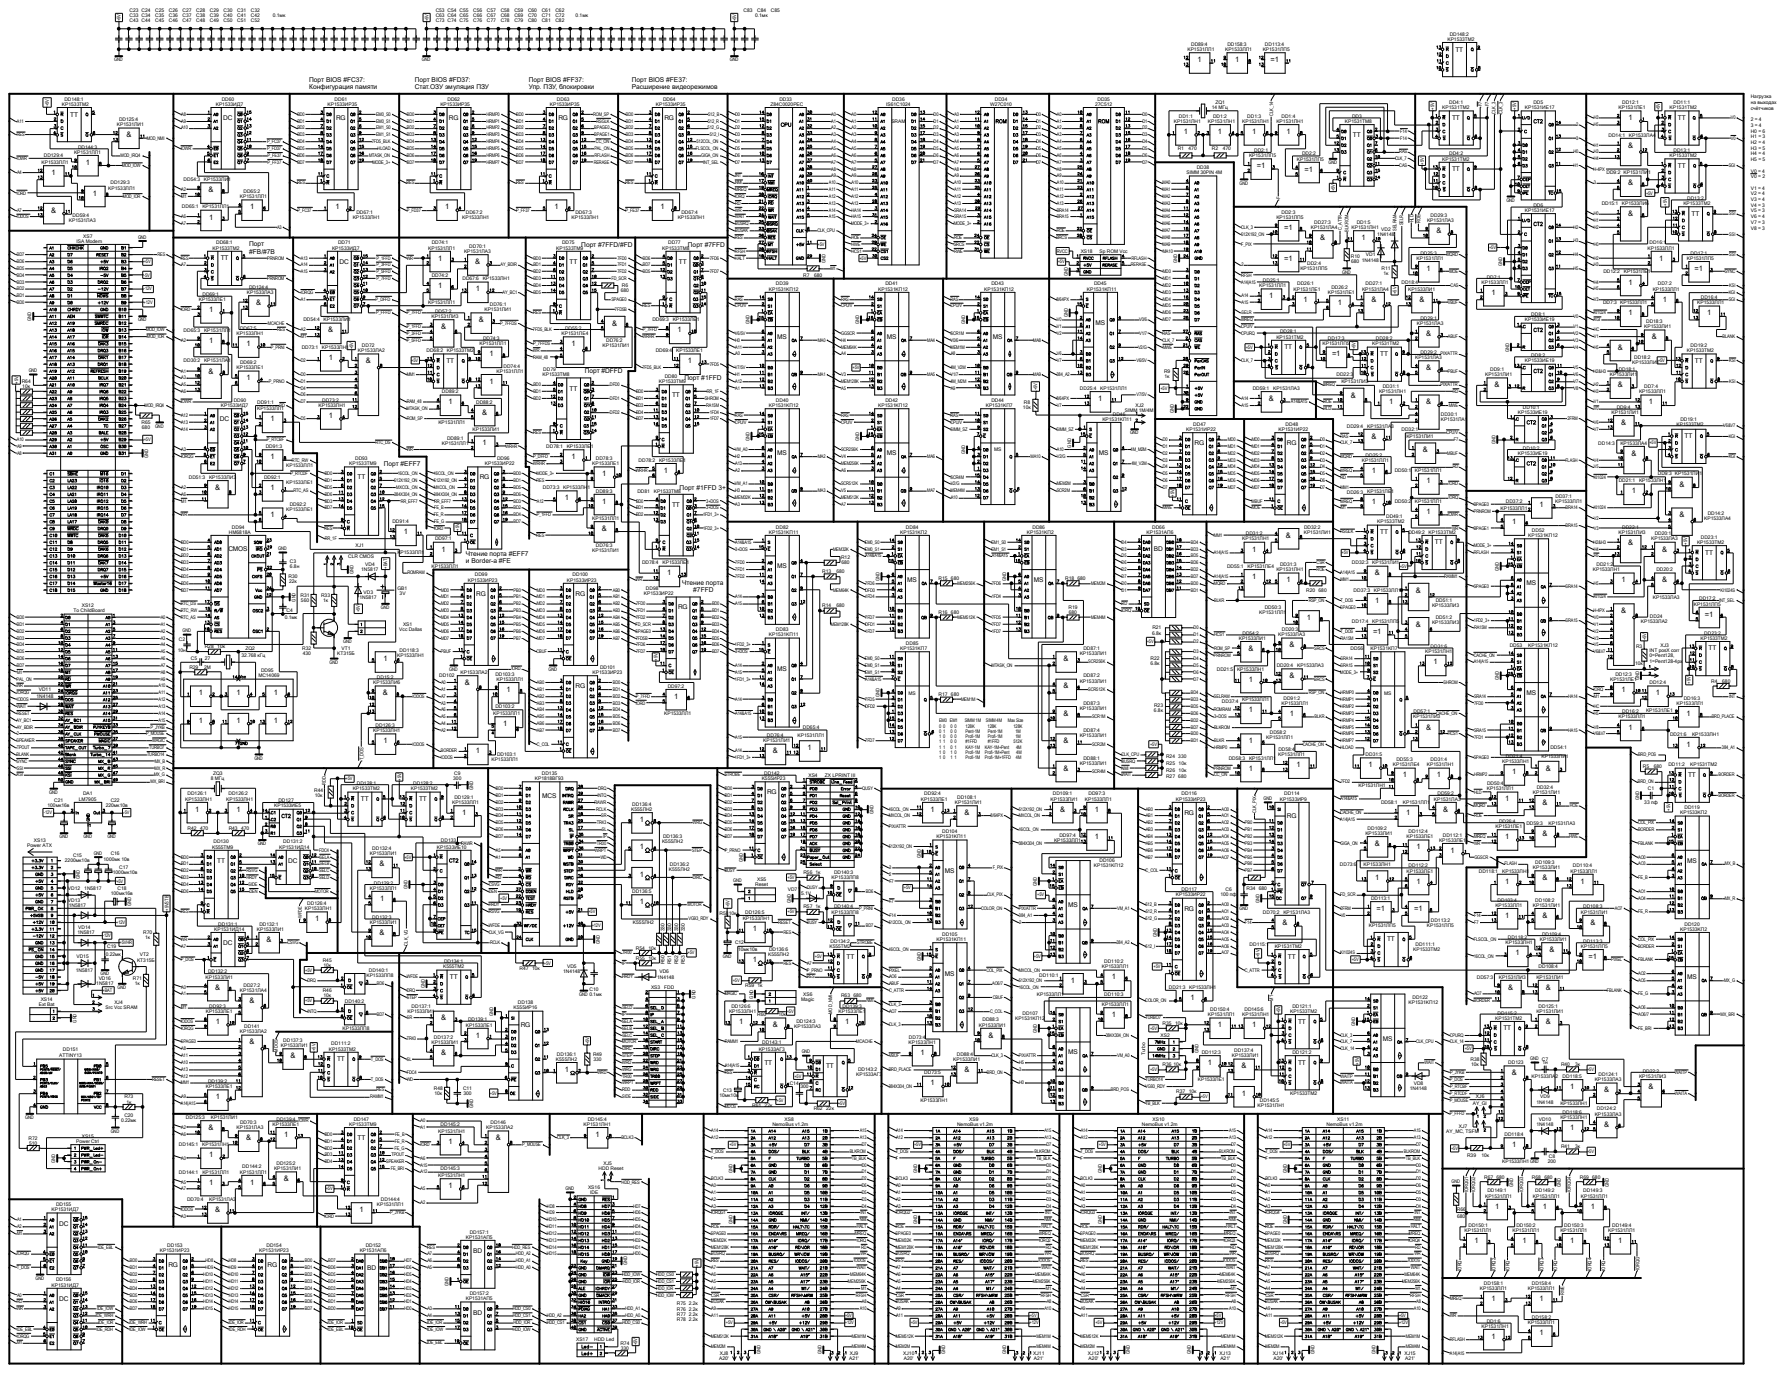
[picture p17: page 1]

Порт BIOS #FD37:
Стат.ОЗУ эмуляция ПЗУ

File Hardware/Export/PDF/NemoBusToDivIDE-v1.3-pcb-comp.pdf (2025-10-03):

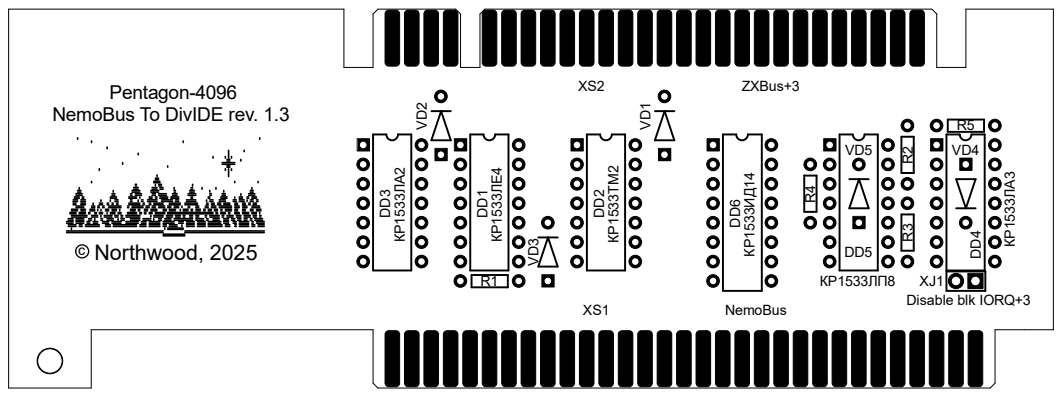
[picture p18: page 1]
c Northwood, 2025; Pentagon-4096; ZXBus+3; NemoBus

NemoBus To DivIDE rev. 1.3

Disable blk IORQ+3

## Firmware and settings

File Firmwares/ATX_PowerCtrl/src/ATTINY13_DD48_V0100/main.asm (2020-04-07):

;----------------------------------------------------------------------------------------------------------------------------
; автор: Тарасов М.Н.
; main.asm  - модуль функций контроллера,  2012г.
; описание: программа управления питанием ATX блока питания компьютера ZXM-Phoenix 1024kb rev05 
; Тип микроконтроллера: ATTINY13
; Частота кварцевого резонатора : 4.800000 MHz
; Модель памяти : Small
; Версия: v1.00  - июнь 2012г.
;----------------------------------------------------------------------------------------------------------------------------
; Описание выводов микроконтроллера:
; PB0 - не используется
; PB1 - выход управления сигналом RESET компьютера
; PB2 - вход кнопки питания
; PB3 - выход управления сигналом POWER ON блока питания
; PB4 - выход управления светодиодом ИНДИКАТОР ПИТАНИЯ 
; PB5 - вход датчика напряжения POWER GOOD от блока питания
;----------------------------------------------------------------------------------------------------------------------------
; Алгоритм работы:
;
; 1. Компьютер не включен. С блока питания ATX приходит напряжение +5SB питания дежурного режима.
;    Действия: 
;	      a) При первоначальном появлении напряжения питания дежурного режима - инициализация внутренних ресурсов контроллера.
;	      б) Установить сигнал RESET в активное состояние лог. "0", светодиодом ИНДИКАТОР ПИТАНИЯ входим в режим мерцания,
;		 на выход POWER ON установим напряжение лог. "0".
;	      в) Основной цикл - опрос датчика напряжения POWER GOOD и мерцание светодиодом ИНДИКАТОР ПИТАНИЯ с переодичнстью 1 сек.
;	         опрос состояния кнопки питания.
;	      г) При при нажатии кнопки питания включаем блок питания путем подачи лог. "1" на выход POWER ON.
;	      д) При появлении активного сигнала на входе POWER GOOD, устанавливаем светодиод ИНДИКАТОР ПИТАНИЯ в режим постоянного свечения 
;                и возврата кнопки питания в ненажатое состояние переходим к режиму работы - Компьютер включен 
; 2. Компьютер включен. 
;    Действия:
;	      а) устанавливаем сигнал RESET в активное состояние лог. "1".
;	      б) Основной цикл - опрос датчика напряжения POWER GOOD, опрос состояния переключателя напряжения.
;	      в) При нажатии кнопки питания устанавливаем сигнал RESET в лог. "0". Если удержание кнопки питания длится более 5 сек
;	         происходит выключение питания путем подачи лог. "0" на выход POWER ON и затем входим в режим 1.б
;		 Если кнопка кнопка была в удержанном состоянии менее 5 сек, то устанавливаем сигнал RESET в лог. "1".  	 
;----------------------------------------------------------------------------------------------------------------------------
; Описание флагов состояния работы микроконтроллера: BYTE_STATUS_FLG
; 0 бит - 
; 1 бит - 
; 2 бит - 
; 5 бит - признак нажатия кнопки (0 - кнопку не нажимали, 1 - кнопку нажали)  
; 6 бит - признак индикации присутствия напряжения (0 - индикация отключена, 1 - индикация включена)
; 7 бит - признак режима ПИТАНИЕ КОМПЬЮТЕРА (0 - выключено, 1 - включено)
;----------------------------------------------------------------------------------------------------------------------------
		        .DEF	BYTE_SAVE_AL    = R0 	;копия регистра AL
		        .DEF	BYTE_SAVE_AH    = R1 	;копия регистра AH
			.DEF	BYTE_SAVE_FLG   = R2    ;копия системного регистра
			.DEF	BYTE_STATUS_FLG = R3    ;флаги состояния работы микроконтроллера
			.DEF	BYTE_LED_COUNT  = R4    ;счетчик тиков для мерцания светодиода когда компьютер выключен

			.DEF	BYTE_BUTTON_FLT = R10	;состояние кнопки - значение фильтра
			.DEF	BYTE_BUTTON_RES = R11	;состояние кнопки - реальное значение
			.DEF	MS_BUT_TIMERL   = R12   ;таймер фильтра кнопки
			.DEF	MS_BUT_TIMERH   = R13
			.DEF	MS_OFF_TIMERL   = R14   ;таймер на выключение компьютера
			.DEF	MS_OFF_TIMERH   = R15

                        .DEF	MS_CLOCKL      	= R20
			.DEF	MS_CLOCKH      	= R21 

			.DEF	DL = R24
			.DEF	DH = R25
			.DEF	CL = R26                ;регистр для передачи параметров в подпрограммы(младший байт)
			.DEF	CH = R27                ;регистр для передачи параметров в подпрограммы(старший байт)
			.DEF	BL = R28                ;регистр для передачи параметров в подпрограммы(младший байт)
			.DEF	BH = R29                ;регистр для передачи параметров в подпрограммы(старший байт)
                        .DEF	AL = R30		;аккумулятор low 
			.DEF	AH = R31                ;            high
			
	            	.INCLUDE "ATTINY13.inc"

			.EQU	TIMER_CLK = 181		;предделитель 256 - 75 CLK/256

			.EQU	BUTTON_CNST_DLY  = 25	;фильтр в 100мс
			.EQU	BUTTON_CNST_OFF  = 1250	;длительность 5 секунд


;-------------------------------------------------------------------------------------------------------
;Описание: Основная программа
;-------------------------------------------------------------------------------------------------------
 			.CSEG
			.ORG	$0000

START:     		
			RJMP 	RESET
			RJMP 	START
	      		RJMP 	START
	      		RJMP 	TIM0_OVF
    	  		RJMP 	START
	      		RJMP 	START
	      		RJMP 	START
	      		RJMP 	START
	      		RJMP 	START
	      		RJMP 	START
		
			.DB	"DD48 ver01.00 by Mick 2012"

RESET:			
			CLI                             ;запрещаем прерывания
			CLR  	AL
			OUT  	EECR,AL
			OUT  	MCUCR,AL
			LDI  	AL,$9F
			OUT  	SPL,AL
			RCALL	CPU_INI_HARD            ;настройка внутренних регистров микроконтроллера
			RCALL	CPU_INI_VARIABLE        ;очистим переменные
			SEI                             ;разрешим прерывания

MAIN_LOOP:
			SBRC	BYTE_STATUS_FLG,7	;проверим работает ли компьютер (питание включено)
			RJMP	MAIN_POWER_ON		;установлен - отслеживаем состояние работающего компьютера
;-------------------------------------------------------------------------------------------------------
;Описание: Компьютер выключен
;-------------------------------------------------------------------------------------------------------
			SBIS	PINB,5			;проверим соcтояние входа POWER GOOD
			RJMP	MAIN_BUTTON_0		;если "0" то уходим на опрос кнопки
			                                ;иначе - POWER GOOD активен
			SBRC	BYTE_STATUS_FLG,6	;проверим зажигали при этом светодиод
			RJMP	MAIN_BUTTON_ON		;установлен - пропустим зажжение светодиода 
			SBI	PORTB,4			;зажжем светодиод индикатор питания
			LDI	AL,$40
			OR	BYTE_STATUS_FLG,AL	;установим признак что светодиод зажжен
MAIN_BUTTON_ON:
			SBRS	BYTE_STATUS_FLG,5	;проверим нажимали при этом кнопку
			RJMP	MAIN_COMPUTER_START	;сброшен - компьютер включили извне
							;иначе - кнопку нажимали
			RCALL	CPU_BUTTON_PROCESSING	;отслеживаем изменение состояние кнопки
			TST	AL
			BREQ	MAIN_LOOP          	;состояние не менялось
			TST	BYTE_BUTTON_RES		;проверим состояние кнопки
			BREQ	MAIN_COMPUTER_START	;кнопку отжали - запускаем компьютер
			RCALL	CPU_CLEAR_STATUS
			RJMP	MAIN_LOOP		;уходим в начало цикла
MAIN_COMPUTER_START:
			LDI	AL,$80
			MOV	BYTE_STATUS_FLG,AL      ;установим признак КОМПЬЮТЕР ВКЛЮЧЕН
			SBI	PORTB,1			;освободим линию RESET
			RJMP	MAIN_LOOP		;уходим в начало цикла

MAIN_BUTTON_0:						;сигнал POWER GOOD неактивен
			RCALL	CPU_BUTTON_PROCESSING	;отслеживаем изменение состояние кнопки
			TST	AL
			BREQ	MAIN_LED_FLASH          ;состояние не менялось - уходим на мерцание светодиода
			TST	BYTE_BUTTON_RES		;проверим состояние кнопки
			BREQ	MAIN_BUTTON_CLEAR	;кнопку отжали раньше времени, сброс признаков
							;иначе кнопку нажали
			LDI	AL,$20
			OR	BYTE_STATUS_FLG,AL	;установим признак что кнопку нажали
			CBI	PORTB,4			;гасим светодиод питания
			SBI	PORTB,3			;активируем POWER ON
			RJMP	MAIN_LOOP		;уходим в начало цикла
MAIN_BUTTON_CLEAR:
			CLR	BYTE_STATUS_FLG		;очистим признаки запуска	
			CBI	PORTB,3			;выключаем POWER ON
MAIN_LED_FLASH:
			LDI	AL,250			;отслеживаем мерцание светодиода питания
			CP	BYTE_LED_COUNT,AL       ;проверим сколько тиков прошло
			BRLO	MAIN_LOOP		;меньше, в начало цикла
			IN	AL,PORTB		;прочитаем текущее состояние светодиода LED
			LDI	AH,$10
			EOR	AL,AH	                ;изменим на противоположное
			OUT	PORTB,AL
			CLR	BYTE_LED_COUNT
			RJMP	MAIN_LOOP
;-------------------------------------------------------------------------------------------------------
;Описание: Компьютер включен
;-------------------------------------------------------------------------------------------------------
MAIN_POWER_ON:						;компьютер включен
			SBIC	PINB,5			;проверим соcтояние входа POWER GOOD
			RJMP	MAIN_BUTTON_1		;если "1" то уходим на опрос кнопки
			                                ;иначе - POWER GOOD не активен, компьютер выключен
			RCALL	CPU_CLEAR_STATUS
			RJMP	MAIN_LOOP		;уходим в начало цикла
			
MAIN_BUTTON_1:						;иначе опрашиваем кнопку
			RCALL	CPU_BUTTON_PROCESSING	;отслеживаем изменение состояние кнопки
			TST	AL
			BREQ	MAIN_BUTTON_2          	;состояние не менялось - посмотрим состояние кнопки
			TST	BYTE_BUTTON_RES		;проверим состояние кнопки
			BREQ	MAIN_BUTTON_UNPRESS	;кнопку отжали - проверим нажимали ли ее до этого 
							;кнопку нажали
			LDI	AL,$20
			OR	BYTE_STATUS_FLG,AL	;установим признак нажатия кнопки
			CBI	PORTB,1			;активируем RESET
			MOV	MS_OFF_TIMERL,MS_CLOCKL ;загрузим таймер выключения
			MOV	MS_OFF_TIMERH,MS_CLOCKH
			RJMP	MAIN_LOOP		;в начало цикла
MAIN_BUTTON_UNPRESS:					;кнопку отжали
			SBRS	BYTE_STATUS_FLG,5	;проверим нажимали при этом кнопку
			RJMP	MAIN_LOOP		;сброшен - кнопку не нажимали, в начало цикла
			LDI	AL,$DF
			AND	BYTE_STATUS_FLG,AL	;очистим признаки нажатия кнопки
			SBI	PORTB,1			;освобождаем линию RESET
			RJMP	MAIN_LOOP			
MAIN_BUTTON_2:						;проверим нажималась ли кнопка
			SBRS	BYTE_STATUS_FLG,5	;проверим нажимали при этом кнопку
			RJMP	MAIN_LOOP		;сброшен - кнопку не нажимали, в начало цикла
			                                ;кнопка нажата
			LDI	BL,LOW (BUTTON_CNST_OFF) ;загрузим константу таймера выключения компьютера
			LDI	BH,HIGH (BUTTON_CNST_OFF)             		
			MOV	CL,MS_OFF_TIMERL        ;загрузим значение таймера задержки
			MOV	CH,MS_OFF_TIMERH
           		RCALL	CPU_CHECK_DELAY         ;сравним с текущим значением таймера
			BRLO	MAIN_LOOP_0		;еще время есть - в начало цикла			
			LDI	AL,$DF
			AND	BYTE_STATUS_FLG,AL	;очистим признаки нажатия кнопки
			CBI	PORTB,3			;время вышло, отключаем POWER ON
MAIN_LOOP_0:
        		RJMP	MAIN_LOOP		;и ждем пока не исчезнет POWER GOOD
;-------------------------------------------------------------------------------------------------------
;Описание: Отслеживание значения кнопки
;Входные параметры: нет
;Выходные параметры: флаг CY =1 если произошло изменение
;-------------------------------------------------------------------------------------------------------
CPU_BUTTON_PROCESSING:
			CLR	AL
			SBIS	PINB,2			;кнопка не нажата
			INC	AL
			CP	AL,BYTE_BUTTON_FLT      ;состояния равны?
			BRNE	CPU_BUTTON_RELOAD	;нет - перезапишем состояние
			CP	BYTE_BUTTON_FLT,BYTE_BUTTON_RES ;сравним с реальным значением
			BRNE	CPU_BUTTON_COMPARE	;не равны - проверим таймер
			CLR	AL
			RET				;иначе выход	
CPU_BUTTON_COMPARE:
			LDI	BL,LOW (BUTTON_CNST_DLY) ;загрузим константу таймера фильтра
			LDI	BH,HIGH (BUTTON_CNST_DLY)             		
			MOV	CL,MS_BUT_TIMERL         ;загрузим значение таймера задержки
			MOV	CH,MS_BUT_TIMERH
           		RCALL	CPU_CHECK_DELAY         ;сравним с текущим значением таймера
			BRLO	CPU_BUTTON_EXIT		;время еще не вышло
			MOV	BYTE_BUTTON_RES,BYTE_BUTTON_FLT ;установим новое значение кнопки
			LDI	AL,1
			RET
CPU_BUTTON_RELOAD:
			MOV	MS_BUT_TIMERL,MS_CLOCKL  ;перегрузим таймер фильтра кнопки
			MOV	MS_BUT_TIMERH,MS_CLOCKH
			MOV	BYTE_BUTTON_FLT,AL	 ;запишем новое состояние
CPU_BUTTON_EXIT:
			CLR	AL
			RET
;-------------------------------------------------------------------------------------------------------
;Описание: Инициализация портов и регистров оборудования микроконтроллера
;Входные параметры: нет
;Выходные параметры: нет
;-------------------------------------------------------------------------------------------------------
CPU_INI_HARD:	
		        LDI	AL,$C1
			OUT	PORTB,AL		;очистим выходы
			LDI	AL,$1A
			OUT	DDRB,AL                 ;выходы 1,3,4 биты
			LDI	AL,$02			;очистка флагов таймеров
			OUT	TIMSK0,AL
			OUT	TIFR0,AL
			LDI	AL,$04			;предделитель CLK/256
			OUT	TCCR0B,AL
			LDI	AL,TIMER_CLK	        ;переполнение 256 - 25 = 231 (4мс)
			OUT	TCNT0,AL
			RET
;-------------------------------------------------------------------------------------------------------
;Описание: Инициализация портов и регистров оборудования микроконтроллера
;Входные параметры: нет
;Выходные параметры: нет
;-------------------------------------------------------------------------------------------------------
CPU_INI_VARIABLE:
			CLR	BYTE_STATUS_FLG
			CLR	BYTE_LED_COUNT
			CLR	BYTE_BUTTON_FLT
			CLR	BYTE_BUTTON_RES
			RET
;-------------------------------------------------------------------------------------------------------
;Описание: Сброс состояний
;Входные параметры: нет 
;Выходные параметры: нет
;-------------------------------------------------------------------------------------------------------
CPU_CLEAR_STATUS:
			CLR	BYTE_STATUS_FLG		;очистим признаки запуска	
			LDI	AL,$C1  		;все выключаем
			OUT	PORTB,AL
			CLR	BYTE_LED_COUNT
			RET
;-------------------------------------------------------------------------------------------------------
;Описание: Подпрограмма проверки истечения задержки по времени
;Входные параметры:  BL,BH - пара регистров константа задержки
;		     CL,CH - пара регистров хранения задержки
;Выходные параметры: Флаг СY - установлен не равны 
;-------------------------------------------------------------------------------------------------------
CPU_CHECK_DELAY:
		  	MOV	DL,MS_CLOCKL
			MOV	DH,MS_CLOCKH
                        SUB	DL,CL
			SBC	DH,CH
			CP	DL,BL			;сравним старшие байты константы и величины задержки	
			CPC	DH,BH                   ;сравним младшие байты константы и величины задержки	
			RET			
;-------------------------------------------------------------------------------------------------------
;Описание: Обработка прерываний от систеного таймера каждые 4мс
;Входные параметры: нет 
;Выходные параметры: нет
;-------------------------------------------------------------------------------------------------------
TIM0_OVF:		
			MOV	BYTE_SAVE_AL,AL         ;сохраним аккумулятор
			IN	AL,SREG
			MOV	BYTE_SAVE_FLG,AL
			IN	AL,TIFR0
			ORI	AL,$02
			OUT	TIFR0,AL
			LDI	AL,TIMER_CLK	
			OUT	TCNT0,AL		;прерывание по таймеру происходит через 4мс 
			INC	MS_CLOCKL
	 		BRNE	TIM0_OVF_2
			INC	MS_CLOCKH
TIM0_OVF_2:
			INC	BYTE_LED_COUNT
		        MOV	AL,BYTE_SAVE_FLG       	; востановим флаг Z
			OUT	SREG,AL
			MOV	AL,BYTE_SAVE_AL         ; востановим аккумулятор
        		RETI			

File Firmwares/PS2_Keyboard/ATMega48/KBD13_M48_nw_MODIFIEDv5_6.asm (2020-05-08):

.include "m48def.inc"
//.include "m8def.inc"

/*
 * Sources written in Atmel AVR Studio 5.1
 *
 * upload using command: avrdude -p atmega8 -c USBasp -U flash:w:KBD_CORRCTED.hex -U lfuse:w:0xCF:m -U hfuse:w:0xC7:m
 */ 

;------------------------------------------------
; set MCU type
; 0 - ATMega8
; 1 - ATMega48/88/168/328
;------------------------------------------------
#define MCU_TYPE 1

#define HOTKEYS 1
/*
1:	Reset = F12
	Magic = Print Screen
	Pause = Pause/Break
	Turbo-7MHz = Scroll Lock
	Turbo-14MHz = Right Shift + Scroll Lock

2:	Reset = Print Screen
	Magic = F12
	Pause = Pause/Break
	Turbo-7MHz = Scroll Lock
	Turbo-14MHz = Right Shift + Scroll Lock
*/

///////////////////////////////////////////////
// Коэффициент таймингов PS2 клавиатуры, MAX=25
// чем выше частота кварца, тем больше коэффициент и наоборот
// не все контроллеры могут работать с кварцами более 20МГц, т.к. Atmega8-16PU, 16Мгц :-D
// но большинство может тянуть 24МГц, а редкие экземпляры могут и 40МГц
.equ TIMING_COEFF	= 15
; 24 for 32 MHz (60000ns/31ns/80 = 24) 31ns 1 cycle time for 32MHz
; 23 for 30 MHz (60000ns/33ns/80 = 23) 33ns 1 cycle time for 30MHz
; 21 for 28 MHz (60000ns/36ns/80 = 21) 36ns 1 cycle time for 28MHz
; 20 for 27 MHz (60000ns/37ns/80 = 20) 37ns 1 cycle time for 27MHz
; 19 for 25 MHz (60000ns/40ns/80 = 19) 40ns 1 cycle time for 25MHz
; 18 for 24 MHz (60000ns/42ns/80 = 18) 42ns 1 cycle time for 24MHz
; 15 for 20 MHz (60000ns/50ns/80 = 15) 50ns 1 cycle time for 20MHz
; 12 for 16 MHz (60000ns/62ns/80 = 12) 62ns 1 cycle time for 16MHz
///////////////////////////////////////////////
;r0 - used
;r1 - used
.def PARITY=r2
;r3 - used
.def CONST00=r4
.def KBD_BYTE_PREV=r5
.def KBD_E0_FLAG=r6
.def CONST80=r7
.def KA08_ROW=r8
.def KA09_ROW=r9
.def KA10_ROW=r10
.def KA11_ROW=r11
.def KA12_ROW=r12
.def KA13_ROW=r13
.def KA14_ROW=r14
.def KA15_ROW=r15
;r16 tmp (used)
.def CONST7F=r17
;r18 tmp (used)
.def KBD_LOOP_CNT=r19
;r20 - used in INT interrupt
.def CONSTFF=r21
.def TURBO_MODE=r22	//Northwood
;r22 - free (used by Northwood for Turbo Mode)
.def KBD_STATE=r23
.def KBD_IND=r24
.def KBD_BYTE=r25

; KBD_STATE  
;		bit 0 symbol shift key (CTRL) released
;		bit 1 indicates #F0 prefix
; 		bit 2 caps shift key (SHIFT) released
; 		bit 3 бит отключения проверки сброса SHIFT статусов
; 		bit 4 symbol shift flag
; 		bit 5 caps shift flag
; 		bit 6 -----
; 		bit 7 Ext Mode set

; KBD_E0_FLAG - bit 7 indicates #E0 prefix

; SRAM MAP
; 0x100-0x1FF - Port #FE data
; 0x200-0x207 - Key Buffer
; 0x208-0x20F - Prepared data for port #FE
; 0x210 - Right Shift pressed


.equ 	RSHIFT_STATUS	= 0x210
.equ	TEMP_SRAM		= 0x211


.CSEG
.ORG	0x0000

;-----------------------------------------------------
; SET PROGRAM INTERRUPT VECTORS
;-----------------------------------------------------
RESET:
rjmp	_RESET			;(1, Power-on/Reset)


///////////////////////////////////////////////////////////////////////////////////////////
// INT 0 Interrupt Handler 4+14 cycles
// 16MHz: 1 cycle = 62ns, 62*9=558ns from falling edge to data set on port B достаточно много получается, может не работать
// 20MHz: 1 cycle = 50ns, 50*9=450ns from falling edge to data set on port B
// 24MHz: 1 cycle = 42ns, 42*9=378ns from falling edge to data set on port B
// 25MHz: 1 cycle = 40ns, 40*9=360ns from falling edge to data set on port B
// 27MHz: 1 cycle = 37ns, 37*9=333ns from falling edge to data set on port B
// 28MHz: 1 cycle = 36ns, 36*9=324ns from falling edge to data set on port B
// 30MHz: 1 cycle = 33ns, 33*9=297ns from falling edge to data set on port B
// 32MHz: 1 cycle = 31ns, 31*9=279ns from falling edge to data set on port B
// Чем быстрее работает это прерывание, тем лучше, а для этого частота кварца должна быть выше!
///////////////////////////////////////////////////////////////////////////////////////////

INT0_Vector:

	in		YL, PinD		; PinD -> YL receive data from bus							; 1 cycle
	
	// ------- 2 cycle both -------------
	sbic	PinC,0x03	; if (PinC.3=0) skip next line (IF KA10=0)				; 1/2 cycle, 2 byte instruction
	bld 	YL, 2		; move bit 3 of port C to bit 2 of data from port D		; 1 cycle, 2 byte instruction
	// ----------------------------------

	ldd		r20, Y+0x00	; put data to r20 from SRAM key table at 0x100+YL			; 2 cycles, 4 byte instruction
	
	//4+5 cycles before set data on port FE
	out		DDRB, r20																; 1 cycle, 2 byte instruction
	rjmp 	INT0_Hander

#if MCU_TYPE == 0

TIMER1_MatchB_Vector:
	rjmp TIMER1_MatchB_Handler

#elif MCU_TYPE == 1

TIMER2_MatchA_Vector:
	nop

TIMER2_MatchB_Vector:
	nop

TIMER2_Ovf_Vector:
	nop

TIMER1_Capt_Vector:
	nop

TIMER1_MatchA_Vector:
	rjmp TIMER1_MatchA_Handler

#endif

INT0_Hander:
	// ------ 3 cycle, 6 bytes
HOLD_BUS: ; hold data on bus while /RDFE=0
	sbis	PinD, 0x02	;if PinD.2=1 skip rjmp
	rjmp	HOLD_BUS
	// --------------

	//out DDRB,CONST00	; turn data bus to HI-Z state								; 1 cycle, 2 byte instruction
	out		DDRB, TURBO_MODE	; turn data bus to HI-Z state, excluding TurboMode bits	; 1 cycle, 2 byte instruction
	reti																			; 4 cycles
///////////////////////////////////////////////////////////////////////////////////////////	14 cycles

#if MCU_TYPE == 0

TIMER1_MatchB_Handler:

#elif MCU_TYPE == 1

TIMER1_MatchA_Handler:

#endif

	sts		TEMP_SRAM, r18
	sts		TCCR1B, CONST00 ;останавливаем счётчик, чтобы больше не считал
	pop		r18			;Перемещаем указатель стека на два адреса возврата раньше,
	pop		r18			;чтобы по reti вернуться не в прерванную подпрограмму, а на 2 ret раньше
	pop		r18
	pop		r18
	lds		r18, TEMP_SRAM
	sec					;Устанавливаем флаг переноса - признак, что CLK от клавиатуры не дождались
	reti

/*	Помигать индикатором на клавиатуре оказалось плохой идеей.
TIMER1_MatchA_Handler:
	cli
	sts		TCNT1H, CONST00
	sts		TCNT1L, CONST00
	sbrc	TURBO_MODE, 0x07
	rcall	SCROLL_IND_FLASH
	sei
	reti
*/

///////////////////////////////////////////////////////////////////////////////////////////
// PROGRAM START
///////////////////////////////////////////////////////////////////////////////////////////

_RESET:

	clr r18
	sts RSHIFT_STATUS, r18
	// Port C setup first for not switching keys (turbo,magic)
	ldi	r18,0x08		; set LOW output on C0-C2,C4-C5 C3 Pull Up
	out	PortC,r18

	// Init constant
	ser CONSTFF			; 0xFF -> CONSTFF
	clr TURBO_MODE		; Turbo Mode Off

	// Port D
	out	PortD,CONSTFF	; all pins with pullup

	// Init constant
	clr	CONST00			; 0x00 -> CONST00

	; disable Analog Comparator ==============================
#if MCU_TYPE == 0
	sbi ACSR,ACD			; for atmega8
#elif MCU_TYPE == 1
	ldi r16,ACD				; for ATMEGA48/88/168/328
	rcall SET_BIT
	out ACSR,r18
#endif	
	;=========================================================

	// init stack pointer 0x45F
	ldi	r16,low(RAMEND)
	out	SPL,r16
	ldi	r16,high(RAMEND)
	out	SPH,r16
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

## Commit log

2020-04-07 MainBoard v5.1, TopBoard v2.2
    [MainBoard-v5.1.SCH, TopBoard-v2.2.SCH, ZXBus+3Adapter.SCH]
2020-04-07 MainBoard v5.5, TopBoard v3.5
    [MainBoard-v5.1.SCH, MainBoard-v5.5.SCH, TopBoard-v2.2.SCH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]
2020-04-07 MainBoard v7.0, TopBoard v4.0
    [MainBoard-v5.5.SCH, MainBoard-v7.0.SCH, TopBoard-v3.5.SCH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]
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2020-04-11 Add A0 to PS2 keyboard access
    [TopBoard-v4.0.SCH]
2020-04-12 Replace Printer internal connector to BH26
    [MainBoard-v7.0.SCH]
2020-04-12 Optimize route for top board
    [MainBoard-v7.0.SCH, TopBoard-v4.0.SCH]
2020-04-14 Optimie rooute for MainBoard PCB
    [TopBoard-v4.0.SCH]
2020-05-08 Replace crystall to ext generator for Atmega-48 for PS2 Keyboard, optimize route for all PCB
    [MainBoard-v7.0.SCH, MainBoard-v7.2.SCH, NemoBusRizer-v1.2.SCH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]
2020-06-08 New revision PCB MainBoard 7.3 - NemoBus v1.2m for DMA Sound support
    [MainBoard-v7.2.SCH, MainBoard-v7.3.SCH]
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2020-06-19 Change vias type for mounting pcb, optimize route MainBoard & TopBoard pcb
    [TopBoard-v4.2.SCH]
2020-07-03 New revision MainBoard 7.4 - Move NemoBus Slots down to 150 nils, add forgot net P_FFFD
    [MainBoard-v7.4.SCH]
2020-07-04 New PNG export files v7.4, optimize route MainBoard
    [MainBoard-v7.3.SCH, MainBoard-v7.4.SCH]
2024-04-27 Last Changes for 7.4
    [TopBoard-v4.2.SCH, ZXBusPlus3-v1.2.SCH]
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2024-04-27 Main memory ports Done
    [MainBoard-v10.1.SCH]
2024-04-27 Addres multiplexing for 128K RAM Done
    [MainBoard-v10.1.SCH]
2024-04-27 Address multiplexing for main RAM 4MB Done
    [MainBoard-v10.1.SCH]
2024-04-28 Multi task mode and blok high RAM Done
    [MainBoard-v10.1.SCH]
2024-04-28 Fix error for port 1FFD+3
    [MainBoard-v10.1.SCH]
2024-04-28 Port EFF7 & CMOS RTC Done
    [MainBoard-v10.1.SCH]
2024-04-28 Read ports #7FFD & #EFF7 Done
    [MainBoard-v10.1.SCH]
2024-04-28 Pixel & Attr buffers, Port for attributes
    [MainBoard-v10.1.SCH]
2024-04-29 All video modes Done
    [MainBoard-v10.1.SCH]
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2024-04-29 Fix error for GigaScreen mode
    [MainBoard-v10.1.SCH]
2024-04-30 Redesign SCH
    [MainBoard-v10.1.SCH]
2024-04-30 Switch CLK CPU & forming WAIT signal
    [MainBoard-v10.1.SCH]
2024-05-01 Redesign for component labels on SCH
    [MainBoard-v10.1.SCH]
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2024-05-02 Improvements for FDC controller - CLC for VG93
    [MainBoard-v10.1.SCH]
2024-05-02 ZX LPRINT III port Done
    [MainBoard-v10.1.SCH]
2024-05-03 Forming Reset & NMI signals Done
    [MainBoard-v10.1.SCH]
2024-05-03 Pull-up CPU lines to +5V
    [MainBoard-v10.1.SCH]
2024-05-03 Small redesign SCH
    [MainBoard-v10.1.SCH]
2024-05-03 Ports for Keyb, Kemston, Mouse, FE-Out
    [MainBoard-v10.1.SCH]
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2024-05-04 NEMO Bus 1.2m Done
    [MainBoard-v10.1.SCH]
2024-05-04 Fix error Turbo block
    [MainBoard-v10.1.SCH]
2024-05-04 Socket From mainboard to childboard Done
    [MainBoard-v10.1.SCH]
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2024-05-05 Optimize for microchips - 1 case left, renumber labels
    [MainBoard-v10.1.SCH]
2024-05-05 Add blocking capacitors for microchips, renumber labels
    [MainBoard-v10.1.SCH]
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2024-05-08 Design rules for SCH, Table of components MB - change encoding to UTF8
    [MainBoard-v10.1.SCH]
2024-05-08 Remove empty nets. Start design PCB MB - place border, mounting holes, ISA & NemoBus slots
    [MainBoard-v10.1.SCH]
2024-05-22 Place all chips on PCB mainboard
    [MainBoard-v10.1.SCH]
2024-05-26 Nemo IDE controller added to Mainboard
    [MainBoard-v10.2.SCH]
2024-05-26 Fix place some labels on PCB
2024-05-27 Place blocking on pcb & remove unnecessary capasitors
    [MainBoard-v10.2.SCH]
2024-05-27 Fix placement some labels on PCB
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2025-08-27 Traceroute main pcb complete
    [MainBoard-v10.2.SCH]
2025-08-31 Top board - add palette for 4096 colors to sch, remove NemoIDE from sch. Main board - small improvements to sch & pcb
    [MainBoard-v10.3.SCH, TopBoard-v5.0.SCH]
2025-09-01 Traceroute both PCB is complete
    [TopBoard-v5.0.SCH]
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2025-09-02 Improvement coder PAL-NTSC - add jumper for separatelly switch 4.43 - 3.58 MHz & PAL-NSTC mode.
    [TopBoard-v5.1.SCH]
2025-09-02 Clear repository from old files
    [MainBoard-v10.0.SCH, MainBoard-v10.1.SCH, MainBoard-v10.2.SCH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]
2025-09-02 Fix silk for TopBoard, add export pdf files
    [TopBoard-v5.1.SCH]
2025-09-02 Small fixes for silk
    [MainBoard-v10.3.SCH]
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2025-09-02 Minor fixes for silk for MainBoard
    [MAINBOARD-V10.3.2.DRL, MAINBOARD-V10.3.2.GBL, MAINBOARD-V10.3.2.GBO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]
2025-09-03 Small PCB design fixes, Table of components
    [MAINBOARD-V10.3.2.DRL, MAINBOARD-V10.3.2.GBL, MAINBOARD-V10.3.2.GBO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]
2025-09-04 Fix error - add jumper simm size, add silk labels for jumpers to pcb
    [MAINBOARD-V10.3.3.DRL, MAINBOARD-V10.3.3.GBL, MAINBOARD-V10.3.3.GBO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]
2025-09-04 Optimize PCB design MainBoard
    [MAINBOARD-V10.3.3.DRL, MAINBOARD-V10.3.3.GBL, MAINBOARD-V10.3.3.GBO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]
2025-09-05 Changed electrolitic capacitors voltage value from 10v to 16v
    [TopBoard-v5.1.SCH]
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2025-09-06 Fixes Freq indicator SCH & PCB, add table of components for freq indicator
    [FreqIndicator.SCH]
2025-09-06 Optimize PCB design for TopBoard
    [TOPBOARD-V5.1.2.DRL, TOPBOARD-V5.1.2.GBL, TOPBOARD-V5.1.2.GBO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]
2025-09-06 Optimize-2 PCB design for TopBoard
    [TOPBOARD-V5.1.2.DRL, TOPBOARD-V5.1.2.GBL, TOPBOARD-V5.1.2.GBO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]
2025-09-06 Add firmware for Freq Indicator
    [FreqInd.obj]
2025-09-09 New version MainBoard v.10.4 - add chip 1533LL1 for fix error - now blocking Static RAM cache if NemoBus device set blocking ROM
    [MAINBOARD-V10.3.3.DRL, MAINBOARD-V10.3.3.GBL, MAINBOARD-V10.3.3.GBO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]
2025-09-11 Flashing mode for Spectrum ROM
    [MAINBOARD-V10.4.3.DRL, MAINBOARD-V10.4.3.GBL, MAINBOARD-V10.4.3.GBO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]
2025-09-13 Fix errors for block rom & projection ram instead rom
    [MAINBOARD-V10.5.4.DRL, MAINBOARD-V10.5.4.GBL, MAINBOARD-V10.5.4.GBO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]
2025-09-15 Fix font for text table near the DD85 on Mainboard sch
    [MainBoard-v10.6.SCH]
2025-09-17 Add forgot connection. Add poligons cutout for gnd & power layers
    [MAINBOARD-V10.6.6.DRL, MAINBOARD-V10.6.6.GBL, MAINBOARD-V10.6.6.GBO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]
2025-09-17 Remove obsolete rizer cards
    [NemoBusRizer-v1.2.SCH, NemoBusToZXBusPlus-v1.1.SCH, ZXBusPlus3-v1.2.SCH]
2025-09-17 Fix pcb for NemoBusToDivIDE card
    [NEMOBUSTODIVIDE-V1.1.2.DRL, NEMOBUSTODIVIDE-V1.1.2.GBL, NEMOBUSTODIVIDE-V1.1.2.GBO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]
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2025-09-18 Rename gerber file GM1 (border outline) to GKO
    [MAINBOARD-V10.6.7.GBL, MAINBOARD-V10.6.7.GBO, MAINBOARD-V10.6.7.GBP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]
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2025-09-23 New version 1.3 for NemoBusToDivIDE adapter - Add jumper for disable IORQ+3 blocking, add connections for some zx-bus signals
    [MainBoard-v10.6.SCH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]
2025-09-24 Fix board edge for edge sockets - cutting right angles
    [NEMOBUSTODIVIDE-V1.3.GBL, NEMOBUSTODIVIDE-V1.3.GBO, NEMOBUSTODIVIDE-V1.3.GBP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]
2025-09-24 Fix PCB design for NemobusToDivIDE
    [NEMOBUSTODIVIDE-V1.3.GBL, NEMOBUSTODIVIDE-V1.3.GBO, NEMOBUSTODIVIDE-V1.3.GBP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]
2025-09-24 Fix error - slot ISA on MainBoard
    [MAINBOARD-V10.6.7.DRL, MAINBOARD-V10.6.7.GBL, MAINBOARD-V10.6.7.GBO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]
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2025-09-28 Fix gerber drilling layer
    [MAINBOARD-V10.6.9.DRL]
2025-09-30 Place hints about jumpers & sockets to PCB silk. Change socket RS-232 to Intel version of the pinout on TopBoard.
    [MAINBOARD-V10.6.9.DRL, MAINBOARD-V10.6.9.GBL, MAINBOARD-V10.6.9.GBO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]
2025-10-03 Remove Blank from palette input, add Blank to classic out without pallette
    [MAINBOARD-V10.6.9.DRL, MAINBOARD-V10.6.9.GBL, MAINBOARD-V10.6.9.GBO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]
2025-10-07 Add RC for phazes clk correction of pixels & border on mainboard
    [MAINBOARD-V10.7.0.DRL, MAINBOARD-V10.7.0.GBL, MAINBOARD-V10.7.0.GBO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]
2025-10-23 Fix TopBoard - VGA & S-Video sockets
    [MainBoard-v10.7.SCH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]
2025-10-23 Fix sockets DE9,DA15, PS/2 on TopBoard
    [TOPBOARD-V5.3.1.DRL, TOPBOARD-V5.3.1.GBL, TOPBOARD-V5.3.1.GBO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]
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
